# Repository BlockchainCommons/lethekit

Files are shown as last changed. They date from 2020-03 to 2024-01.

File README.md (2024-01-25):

# Blockchain Commons LetheKit

**Open source DIY hardware box for offline cryptographic tools**

### _by [Ken Sedgwick](https://www.github.com/ksedgwic), [Gorazd Kovacic](https://www.github.com/gorazdko), and [Christopher Allen](https://www.github.com/ChristopherA)_

* &nbsp;&nbsp; ***part of the [crypto commons](https://github.com/BlockchainCommons/crypto-commons/blob/master/README.md) technology family***
*  ***part of the [gordian](https://github.com/BlockchainCommons/gordian/blob/master/README.md) technology family***

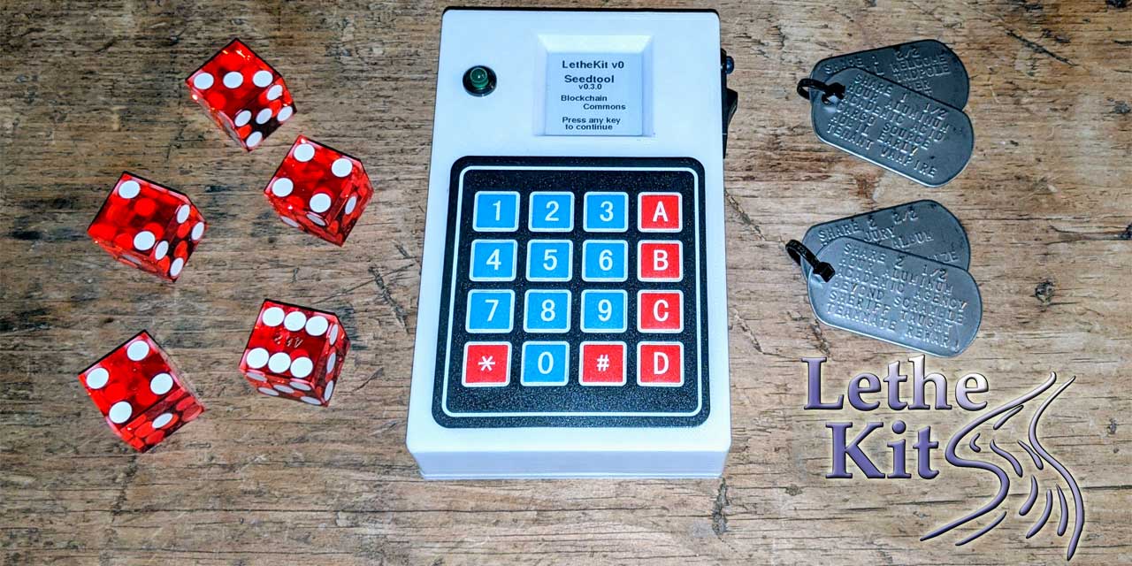
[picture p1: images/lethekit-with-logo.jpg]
LetheKit


*LetheKit* is a do-it-youself platform for performing various sensitive cryptographic operations on an offline airgapped device. It uses no WiFi or Bluetooth which could leak information and contains no local storage, and when the device is turned off it forgets any sensitive data stored in RAM. Thus the name Lethe (_lee-thee_), from the [mythological river](https://en.wikipedia.org/wiki/Lethe) of forgetfulness and oblivion.

## Additional Information

The following files contain everything you need to set up your *LetheKit* hardware and install its software.

* The [Parts List](doc/parts-list.md) describes all needed parts.
* The [Case Information](case) contains STL files for 3-D printing.
* The [Lethekit Assembly Instructions](doc/assembly.md) show how to put it together.
* The [Lethekit Installation Instructions](doc/installation.md) show how to install LetheKit in your Arduino development environment.
* The [Seedtool Installation Instructions](seedtool/doc/build.md) show to install Seedtool on your *LetheKit* using the Arduino IDE.
* The [Seedtool Application Instuctions](seedtool/README.md) describe how to generate and recover
[BIP-32](https://github.com/bitcoin/bips/blob/master/bip-0032.mediawiki) HD wallet master seeds in [BIP-39](https://github.com/bitcoin/bips/blob/master/bip-0039.mediawiki) and [SSKR](https://github.com/BlockchainCommons/Research/blob/master/papers/bcr-2020-011-sskr.md) formats.
* [Blog Post Overview](https://www.blockchaincommons.com/projects/Releasing-LetheKit/)

Your LetheKit can be charged or recharged with a micro-USB connection.

## Gordian Principles

**Gordian LetheKit** is a hardware exemplar meant to display the [Gordian Principles](https://github.com/BlockchainCommons/Gordian#gordian-principles), which are philosophical and technical underpinnings to Blockchain Commons' Gordian technology. This includes:

* **Independence.** LetheKit ensures that you're in total control of your seeds.
* **Privacy.** LetheKit is totally offline.
* **Resilience.** LetheKit depends on you for its resilience, since you must back up your words or codes.
* **Openness.** LetheKit communicates through airgaps via URs and QRs, for maximum interoperability.

Blockchain Commons apps do not phone home and do not run ads. Some are available through various app stores; all are available in our code repositories for your usage.

## Status - Unsupported

*LetheKit* is no longer being actively supported by Blockchain Commons. It may not be up to date with recent security notices, and it may not work as originally intended or even at all. This repo remains solely for historical purposes. Use at your own risk. 

If you'd like to become a new lead for the project, please file an issue.

## Origin, Authors, Copyright & Licenses

Unless otherwise noted (either in this [/README.md](./README.md) or in the file's header comments) the contents of this repository are Copyright © 2020 by Blockchain Commons, LLC, and are [licensed](./LICENSE) under the [spdx:BSD-2-Clause Plus Patent License](https://spdx.org/licenses/BSD-2-Clause-Patent.html).

In most cases, the authors, copyright, and license for each file reside in header comments in the source code. The table below attempts to attribute accurately for files without such information.

This table below also establishes provenance (repository of origin, permalink, and commit id) for files included from repositories that are outside of this one. Contributors to these files are listed in the commit history for each repository, first with changes found in the commit history of this repo, then in changes in the commit history of their repo of their origin.

| File | From | Commit | Authors & Copyright (c) | License |
| --- | --- | --- | --- | --- |
| Cryptosuite | [https://github.com/ksedgwic/Cryptosuite](https://github.com/ksedgwic/Cryptosuite) | ae0e3eeb4eb00c53fe235e0c34f77ade11f1982a | 2010 Peter Knight | <none> |
| bip39 | [https://github.com/ksedgwic/bip39](https://github.com/ksedgwic/bip39) | 9b8fa3c7d145c39558c2534f6cf40879477d93a1 | 2018 Chris Howe | [MIT License](https://github.com/ksedgwic/bip39/blob/master/LICENSE) |
| TRNG-for-ATSAMD51J19A-Adafruit-Metro-M4- | [https://github.com/SapientHetero/TRNG-for-ATSAMD51J19A-Adafruit-Metro-M4-](https://github.com/SapientHetero/TRNG-for-ATSAMD51J19A-Adafruit-Metro-M4-) | 17d5e36cd922ce7df8047d9c89633dca9b5ae122 | 2019 Ron Sutton | [MIT License](https://github.com/SapientHetero/TRNG-for-ATSAMD51J19A-Adafruit-Metro-M4-/blob/master/LICENSE.txt) |
| libwally-core | [https://github.com/ElementsProject/libwally-core](https://github.com/ElementsProject/libwally-core) | e0d0634aea716d813744326ea6c7590eb9fc381c | Jon Griffiths (Blockstream) 2016 | [BSD/MIT license](https://github.com/ElementsProject/libwally-core/blob/master/LICENSE) |
| Library-arduino-cbor | [https://github.com/jjtara/Library-Arduino-Cbor](https://github.com/jjtara/Library-Arduino-Cbor) | 996bf4a853513ee1fb94286691209a067c915bfb | jjtara 2014 | [Apache license](https://github.com/jjtara/Library-Arduino-Cbor/blob/master/LICENSE) |
| ArduinoSTL | [https://github.com/mike-matera/ArduinoSTL](https://github.com/mike-matera/ArduinoSTL) | 7411816e2d8f49d96559dbaa47e327816dde860c | Mike Matera 1999 | [GNU LGPL](https://github.com/mike-matera/ArduinoSTL/blob/master/LICENSE) |

### Dependencies

To build the *LetheKit* you'll need to use the following exterinal tools:

- [The Arduino IDE](https://www.arduino.cc/en/main/software)

The following internal Blockchain Commons projects are leveraged by *LetheKit*:

- [BlockchainCommons/bc-crypto-base](https://github.com/blockchaincommons/bc-crypto-base) — Well-Reviewed and Audited Cryptographic Functions for Use in Blockchain Commons Software Projects
- [BlockchainCommons/bc-shamir](https://github.com/BlockchainCommons/bc-shamir) - C Implementation of Shamir Secret Sharing for use in Blockchain Commons Software Projects
- [BlockchainCommons/bc-bytewords](https://github.com/BlockchainCommons/bc-bytewords) - C library for encoding and decoding Bytewords.
- [BlockchainCommons/bc-sskr](https://github.com/BlockchainCommons/bc-sskr) - Implementation of Sharded Secret Key Reconstruction (SSKR)

### Derived from ...

The *LetheKit* project was inspired by:

- [Bitcoin 2019 Conference Tutorial](https://github.com/arcbtc/bitcoin2019conf), by [Ben Arc](https://github.com/arcbtc), which provided a fully functional starting point using similar hardware.

### Used with ...

These are other projects that work with or leverage *LetheKit*.

- (submit a PR to this repo list your project)

## Financial Support

*LetheKit* (lee-thee kit) is a project of [Blockchain Commons](https://www.blockchaincommons.com/). We are proudly a "not-for-profit" social benefit corporation committed to open source & open development. Our work is funded entirely by donations and collaborative partnerships with people like you. Every contribution will be spent on building open tools, technologies, and techniques that sustain and advance blockchain and internet security infrastructure and promote an open web.

To financially support further development of *LetheKit* and other projects, please consider becoming a Patron of Blockchain Commons through ongoing monthly patronage as a [GitHub Sponsor](https://github.com/sponsors/BlockchainCommons). You can also support Blockchain Commons with bitcoins at our [BTCPay Server](https://btcpay.blockchaincommons.com/).

### Project Sponsors

Thanks to our project sponsors for their support of *LetheKit*:
  


[**Keystone**](https://keyst.one/) is the manufacturer of the Keystone Hardware Wallet and the Keystone Tablets. Their focus is on uncompromising security and ease of use, taking human error into consideration, skyrocketing attack costs, reducing burdens of proof, and avoiding single points of failure.
  
## Contributing

We encourage public contributions to this project through issues and pull requests! Please review [CONTRIBUTING.md](./CONTRIBUTING.md) for details on our development process. All contributions to this repository require a GPG signed [Contributor License Agreement](./CLA.md).

### Discussions

The best place to talk about Blockchain Commons and its projects is in our GitHub Discussions areas.

[**Gordian User Community**](https://github.com/BlockchainCommons/Gordian/discussions). For users of the Gordian reference apps, including [Gordian Coordinator](https://github.com/BlockchainCommons/iOS-GordianCoordinator), [Gordian Seed Tool](https://github.com/BlockchainCommons/GordianSeedTool-iOS), [Gordian Server](https://github.com/BlockchainCommons/GordianServer-macOS), [Gordian Wallet](https://github.com/BlockchainCommons/GordianWallet-iOS), and [SpotBit](https://github.com/BlockchainCommons/spotbit) as well as our whole series of [CLI apps](https://github.com/BlockchainCommons/Gordian/blob/master/Docs/Overview-Apps.md#cli-apps). This is a place to talk about bug reports and feature requests as well as to explore how our reference apps embody the [Gordian Principles](https://github.com/BlockchainCommons/Gordian#gordian-principles).

[**Blockchain Commons Discussions**](https://github.com/BlockchainCommons/Community/discussions). For developers, interns, and patrons of Blockchain Commons, please use the discussions area of the [Community repo](https://github.com/BlockchainCommons/Community) to talk about general Blockchain Commons issues, the intern program, or topics other than those covered by the [Gordian Developer Community](https://github.com/BlockchainCommons/Gordian-Developer-Community/discussions) or the 
[Gordian User Community](https://github.com/BlockchainCommons/Gordian/discussions).

### Other Questions & Problems

As an open-source, open-development community, Blockchain Commons does not have the resources to provide direct support of our projects. Please consider the discussions area as a locale where you might get answers to questions. Alternatively, please use this repository's [issues](./issues) feature. Unfortunately, we can not make any promises on response time.

If your company requires support to use our projects, please feel free to contact us directly about options. We may be able to offer you a contract for support from one of our contributors, or we might be able to point you to another entity who can offer the contractual support that you need.

### Credits

The following people directly contributed to this repository. You can add your name here by getting involved; the first step is to learn how to contribute from our [CONTRIBUTING.md](./CONTRIBUTING.md) documentation.

| Name | Role | Github | Email | GPG Fingerprint |
| --- | --- | --- | --- | --- |
| Christopher Allen | Principal Architect | [@ChristopherA](https://github.com/ChristopherA) | \<ChristopherA@LifeWithAlacrity.com\> | FDFE 14A5 4ECB 30FC 5D22  74EF F8D3 6C91 3574 05ED |
| Ken Sedgwick | Original Author, Occasional Contributor  | [@ksedgwic](https://github.com/ksedgwic) | \<ken@bonsai.com\> | 4695 E5B8 F781 BF85 4326 9639 BBFC E515 8602 5550  |
| Gorazd Kovacic | developer  | [@gorazdko](https://github.com/gorazdko)  | \<gorazdko@gmail.com\>  | 41F0 EA16 99A7 4C1E 2FA4 1B53 8CF9 6BC3 FF9D BBCE  |

## Responsible Disclosure

We want to keep all our software safe for everyone. If you have discovered a security vulnerability, we appreciate your help in disclosing it to us in a responsible manner. We are unfortunately not able to offer bug bounties at this time.

We do ask that you offer us good faith and use best efforts not to leak information or harm any user, their data, or our developer community. Please give us a reasonable amount of time to fix the issue before you publish it. Do not defraud our users or us in the process of discovery. We promise not to bring legal action against researchers who point out a problem provided they do their best to follow the these guidelines.

### Reporting a Vulnerability

Please report suspected security vulnerabilities in private via email to ChristopherA@LifeWithAlacrity.com (do not use this email for support). Please do NOT create publicly viewable issues for suspected security vulnerabilities.

The following keys may be used to communicate sensitive information to developers:

| Name | Fingerprint |
| --- | --- |
| Christopher Allen | FDFE 14A5 4ECB 30FC 5D22  74EF F8D3 6C91 3574 05ED |

You can import a key by running the following command with that individual’s fingerprint: `gpg --recv-keys "<fingerprint>"` Ensure that you put quotes around fingerprints that contain spaces.

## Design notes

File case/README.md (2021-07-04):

# LetheKit 3D Case

The LetheKit case can be 3D printed from the STL files in
this directory.  One print of each of the following is required:

* [body.stl](body.stl) — the main body of the LetheKit.

* [cover.stl](cover.stl) — the cover for the LetheKit.

* [shield.stl](shield.stl) — an internal component that protects the battery.

The case is designed with [Blender](https://www.blender.org):

* [case.blend](case.blend)

## Printing
### Printing Services
The following printing services have been used:

| Service | Material | Notes |
|---|---|---|
| [Hubs](https://hubs.com) | PA12 (SLS) 100&mu; | "thin walls" and "intersecting faces" warnings can be ignored |

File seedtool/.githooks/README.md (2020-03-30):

This set of git hooks maintains the state of `seedtool/gitrevision.h`.
In order to enable this feature one must execute the following command
anywhere in the seedtool directory:

    ./enable-gitrevision-hooks.sh

A default `seedtool/gitrevision.h` is checked in so folks who use a
tarball or other means will be able to compile.  It has placeholders
for the defined constants.

The `post-checkout`, `post-commit`, and `post-merge` hooks write the
following current information (samples below) to the
`seedtool/gitrevision.h` file:

```
#define GIT_BRANCH "revinfo"
#define GIT_SHORT_HASH "cdb54bd"
#define GIT_REV_COUNT "29"
#define GIT_LATEST_TAG "v0.1.0"
```

The `pre-commit` hook overwrites any generated `seedtool/gitrevision.h`
with the placeholders prior to commit so the placeholders version is
always checked in.

It is, of couurse, impossible to check in the correct current values
because those values depend on the hash of those value ...

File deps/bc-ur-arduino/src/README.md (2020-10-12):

## BC-UR-ARDUINO

This library is a version of https://github.com/BlockchainCommons/bc-ur ported to work
with Arduino.

## Status

Currently, it supports the UR/Fountain encoding, but decoding is not yet implemented.

## Dependencies

* [bc-crypto-base](https://github.com/BlockchainCommons/bc-crypto-base)
* [Library-Arduino-Cbor](https://github.com/jjtara/Library-Arduino-Cbor)
* [ArduinoSTL](https://github.com/mike-matera/ArduinoSTL)

Make sure to install the latest versions from Github.
I

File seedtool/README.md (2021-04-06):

# Seedtool Application Instructions

The *seedtool* utility allows you to generate and recover
[BIP-32](https://github.com/bitcoin/bips/blob/master/bip-0032.mediawiki)
HD wallet master seeds using
[BIP-39](https://github.com/bitcoin/bips/blob/master/bip-0039.mediawiki)
and
[SSKR](https://github.com/BlockchainCommons/Research/blob/master/papers/bcr-2020-011-sskr.md)
formats. In addition, it supports viewing extended keys and addresses in different formats.

This guide assumes you have successfully completed with [Seedtool Installation Instructions](doc/build.md).

## "No Seed" Functions

There are 4 ways to insert a seed into the *seedtool*:  
A - Generate seed with Dice  
B - Restore seed from BIP39  
C - Restore seed from SSKR  
D - Complete a randomly constructed BIP39 sentence

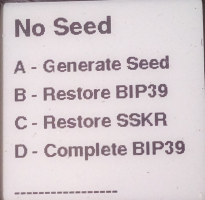
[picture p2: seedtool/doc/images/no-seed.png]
No Seed Menu


### Seed Generation with Dice

By rolling dice and typing the values, you can gather enough auditable entropy to generate a secure master seed. Rolling 50 dice gathers
roughly 128 bits of entropy.

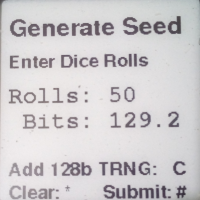
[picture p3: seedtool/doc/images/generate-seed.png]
Generate Seed


If you press C, 128 bits of TRNG entropy will be mixed in:

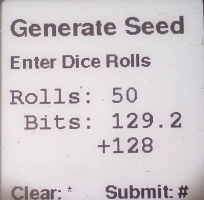
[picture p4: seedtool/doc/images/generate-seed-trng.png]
Generate Seed


### BIP-39 Key Recovery

You can insert a key into the *seedtool* by entering its BIP-39
recovery mnemonic passphrase.  From there you can generate SSKR
shares.

BIP-39 Restore

### SSKR Recovery

If you possess enough shares of a SSKR set, you can recover the
master seed with *seedtool*.  From there you can generate the BIP-39
mnemonic passphrase which will allow you to use it with most wallets.

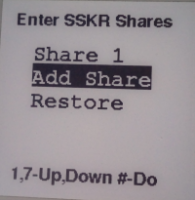
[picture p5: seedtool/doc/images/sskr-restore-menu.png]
SSKR Recovery Menu
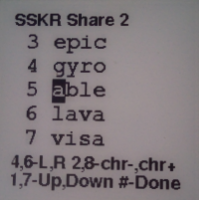
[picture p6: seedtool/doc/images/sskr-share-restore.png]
SSKR Share Entry
 

### Completing a randomly constructed BIP39 sentence

This is a way to generate your own seed without relying on hardware or software. See [instructions](doc/bip39_sentence_completion.md)

## Functions with a Seed

Once you have a seed through any of the prior flows, you can create
BIP-39 and SSKR mnemonic passphrases. In addition, you can view extended public and private
keys, wallet addresses etc. 

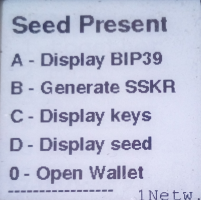
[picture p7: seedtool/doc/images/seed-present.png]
Seed Present Menu


### BIP-39 Generation

The BIP-39 phrase is displayed and can be backed up in a secure
offline fashion (e.g., hammering into metal).

BIP-39 View

### SSKR Generation

SSKR requires some configuration choices to determine total number of shares
and the required number of shares present to recover.

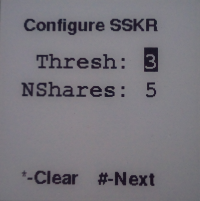
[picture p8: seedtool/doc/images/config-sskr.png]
SSKR Generation Config
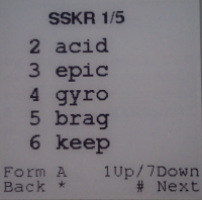
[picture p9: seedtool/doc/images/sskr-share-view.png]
SSKR Share View
 

You can choose among different formats:  
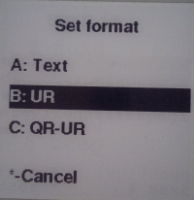
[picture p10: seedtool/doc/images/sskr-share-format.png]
SSKR Share Format

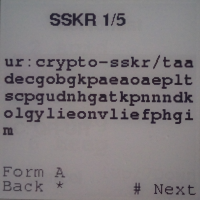
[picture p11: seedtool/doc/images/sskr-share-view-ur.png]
SSKR Share View UR
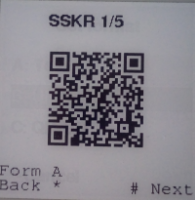
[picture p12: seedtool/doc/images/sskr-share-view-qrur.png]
SSKR Share View QRUR
 

### Displaying Keys

Extended public and private keys (XPUBs and XPRIVs) can be shown in different formats (base58, UR, QR) with different
options: slip132, with derivation path and privkey. If privkey is selected, an extended private key (XPRIV) is shown. Derivation path can be manually set or chosen among standard ones: *native segwit*, *nested segwit* and *cosigner*. Cosigner is the one that can be used in multisignature setups.

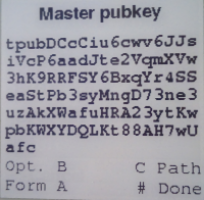
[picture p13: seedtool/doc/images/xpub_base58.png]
XPUB BASE58

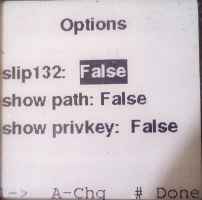
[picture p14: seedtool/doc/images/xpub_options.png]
XPUB OPTIONS

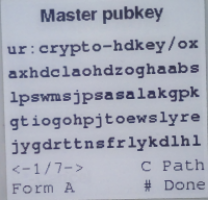
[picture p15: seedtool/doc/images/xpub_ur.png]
XPUB UR


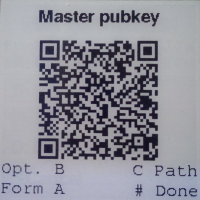
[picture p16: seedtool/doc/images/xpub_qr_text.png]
XPUB OPTIONS

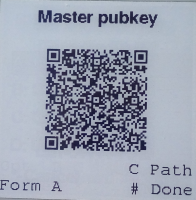
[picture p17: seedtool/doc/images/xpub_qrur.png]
XPUB OPTIONS

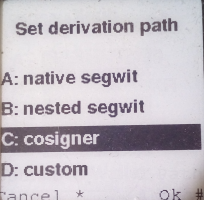
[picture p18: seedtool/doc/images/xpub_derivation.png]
XPUB DERIVATION


### Displaying Seed

You can choose to export seed in UR or QR-UR format.

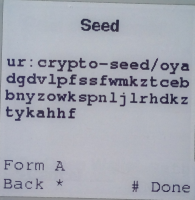
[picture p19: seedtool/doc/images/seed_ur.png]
seed ur

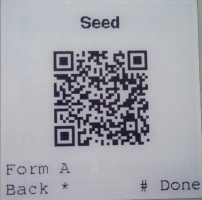
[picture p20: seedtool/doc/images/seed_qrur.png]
seed qrur


### Displaying Addresses

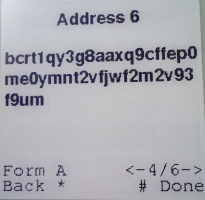
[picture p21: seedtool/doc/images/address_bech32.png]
ADDR TEXT
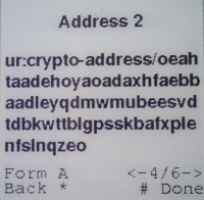
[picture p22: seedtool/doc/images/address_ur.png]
ADDR ur
 
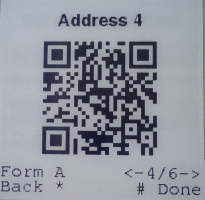
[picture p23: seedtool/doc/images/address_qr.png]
ADDR qr
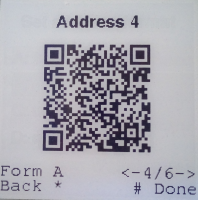
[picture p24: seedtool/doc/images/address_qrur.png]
ADDR qrur
 
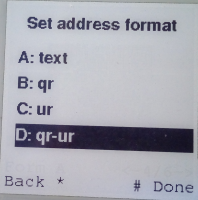
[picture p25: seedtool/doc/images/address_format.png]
ADDR format


A wallet can be exported in the 4 different formats (text, QR, UR and QR-UR):

wallet export wallet export text
wallet export text wallet export text

### Setting network

By pressing 1 in `Seed Present` menu, you can choose among `mainnet`, `testnet` and `regtest`:

wallet export text

## Common Workflows

There are several common key management workflows that *seedtool* is
useful for.

### Generate a New Wallet

By using dice to generate a BIP-39 mnemonic passphrase, you can avoid
trusting a particular hardware vendor's hardware.
[See: RNG subversion](https://en.wikipedia.org/wiki/Random_number_generator_attack#RNG_subversion)

To execute this flow with *seedtool*:
1. Generate a new master seed using 50+ die rolls.
2. Record your master BIP-39 backup in a secure manner (hammer into metal).
   This BIP-39 backup may be restored into most other wallets for common use.
3. Optionally create a SSKR sharded backup set which can serve as
   long-term cold storage.
   
### Generate a SSKR Backup Set for an Existing Wallet

If you've already got a wallet in use, and have the BIP-39 backup for
it, you can generate a SSKR backup set as well:
1. Restore your seed in *seedtool* using your BIP-39 backup.
2. Create a SSKR sharded backup.

### Recover a Master Seed from SSKR Backup Shards

If you need to recover your master seed and have enough shards from a
SSKR backup set:
1. Recover the master seed from the SSKR shards.
2. Create a BIP-39 mnemonic which may then be directly restored into
   most wallets for use.

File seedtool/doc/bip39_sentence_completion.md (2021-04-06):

## BIP39 Sentence Completion

Option `D` (`Complete BIP39`) allows you to
complete a randomly constructed BIP39 sentence. This means that your seed, keys and wallet creation does not rely on hardware nor software but entirely on a randomized procedure conducted by yourself tossing coins. It is true however that the LetheKit completes the last word, i.e. `checksum word`, so that mnemonic sentence can be correctly parsed.



### Procedure

First print out the following table and prepare a coin.



To randomly choose a BIP39 word you have to toss a coin 11 times and fill out a row in the table. For heads you can write 1 and for tails 0.

For example if your first eleven throws are:

`heads` `tails` `tails` `heads` `tails` `heads` `heads` `tails` `tails` `tails` `heads`

then your first row should look like this:



Coin tosses in every row represent a binary number which can be converted to a BIP39 word with the help of a [lookup table](https://www.rudefox.io/custody/walkthrough/create-seed/lookup-tables.pdf)



You have to repeat the procedure 12 times to fill out the table and obtain a full mnemonic sentence of 12 words. Then input all the words into LetheKit



When `done` LetheKit will ask you if your procedure was truly randomized.

⚠️ : If the procedure is not randomized, i.e. the words are not obtained by flipping a coin, the mnemonic sentence is insecure and leads to a loss of funds.



After confirmation, LetheKit will show you the completed BIP39 sentence, i.e. the last word (i.e. `checksum word`) will be transformed to make the sentence complete, while the first eleven words will stay the same.



At this point you have to update the last word on your sheet:



When done, LetheKit will ask you whether you have updated the last word on your sheet?



By confirming with `yes`, LetheKit will generate a seed, keys and a wallet.

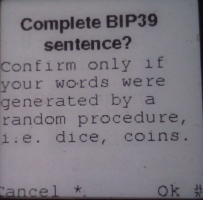
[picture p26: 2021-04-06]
seedtool/doc/images/complete_bip39.png

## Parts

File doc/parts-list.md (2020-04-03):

LetheKit Parts List
================================================================

| Supplier | Description | Quantity | Price |
|---|---|---:|---:|
| Waveshare  | [Waveshare 200x200, 1.54inch E-Ink display module](https://www.waveshare.com/1.54inch-e-paper-module.htm) | 1 | $15.99 |
| AliExpress | [16 Key Membrane Switch Keypad](https://www.aliexpress.com/item/32874565775.html) | 1 |  $0.60 |
| SparkFun | [SparkFun Thing Plus - SAMD51](https://www.sparkfun.com/products/14713) | 1 | $19.95 |
| SparkFun | [Lithium Ion Battery - 2Ah](https://www.sparkfun.com/products/13855) | 1 | $12.95 |
| SparkFun | [LED - Basic Green 5mm](https://www.sparkfun.com/products/9592) | 1 |  $0.35 |
| SparkFun | [LED - Basic Blue 5mm](https://www.sparkfun.com/products/11372) | 1 |  $0.55 |
| SparkFun | [LED Holder - 5mm](https://www.sparkfun.com/products/11840) | 2 |  $1.00 |
| SparkFun | [Jumper Wires](https://www.sparkfun.com/products/12796) | 1 |  $1.95 |
| SparkFun | [Break Away Male Headers - Right Angle](https://www.sparkfun.com/products/553) | 1 |  $1.95 |
| Pololu | [Rocker Switch](https://www.pololu.com/product/1406) | 1 |  $0.75 |
| McMaster | [Flat Head Thread-Forming Screws, No. 6, 1/2"](https://www.mcmaster.com/96068a153) | 4 |  $0.23 |
| McMaster | [Phillips Rounded Head Thread-Forming Screws, No. 2, 3/16"](https://www.mcmaster.com/99461A710) | 6 |  $1.46 |
| McMaster | [Push-In Bumpers](https://www.mcmaster.com/9544k12) | 4 |  $0.30 |
| | [3D Printed Case](../case/README.md) | 1 | |
| | [3D Printed Cover](../case/README.md) | 1 | |
| | [3D Printed Battery Shield](../case/README.md) | 1 | |
| | **TOTAL** | | $58.03 |

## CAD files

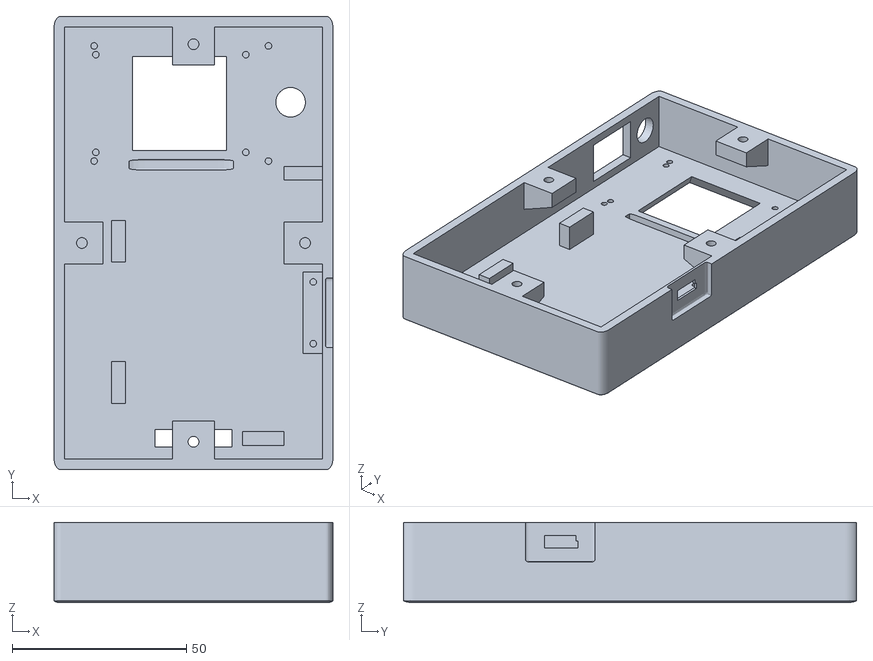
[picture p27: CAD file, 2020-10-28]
case/body.stl
80.0 x 130.0 x 23.0

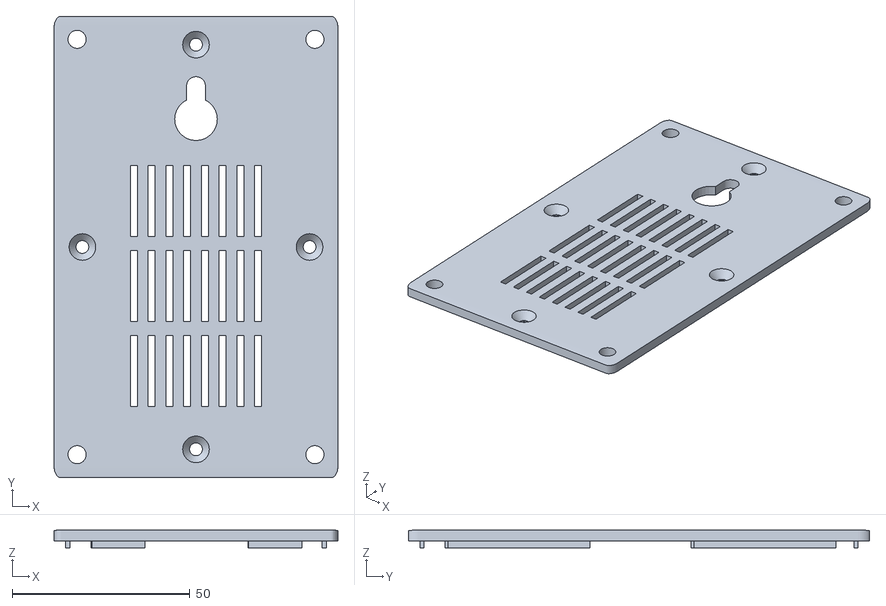
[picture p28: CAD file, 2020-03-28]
case/cover.stl
80.0 x 130.0 x 5.00

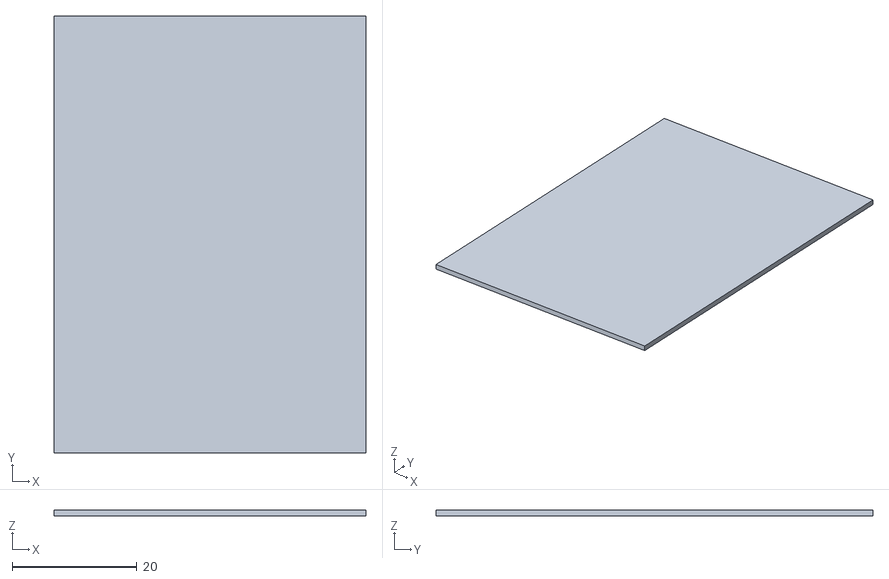
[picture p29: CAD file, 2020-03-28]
case/shield.stl
50.0 x 70.0 x 1.00

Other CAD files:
case/case.blend

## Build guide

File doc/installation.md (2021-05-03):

## LetheKit Installation Instructions

These instructions describe how to install LetheKit into your local
development environment.

LetheKit provides a collection of security modules (libraries) that
work well together. You install them into your local Arduino
development environment and then build the provided sample applications or
develop your own applications before uploading them to your SAMD51.

### Installing Arduino IDE

If you don't already have the *Arduino IDE* installed (recommended v1.8.13) in your local development environment, here are the instructions:

- For macOS we recommend using `$ brew cask install arduino` which will install the Arduino.app in your `/Applications/` folder.
- For Linux users we recommend installing with:
```bash
$ wget https://downloads.arduino.cc/arduino-1.8.13-linux64.tar.xz
$ tar -xvf arduino-1.8.13-linux64.tar.xz
$ cd arduino-1.8.13
$ ./install.sh # sudo ./install.sh
```

### Installing Toolchain for SAMD51

This is an excerpt from [SAMD51 Thing Plus Hookup Guide](https://learn.sparkfun.com/tutorials/samd51-thing-plus-hookup-guide/setting-up-the-arduino-ide):

- In the Arduino IDE, open **Preferences** (**Arduino** > **Preferences**), find the  **Additional Board Manager URLs** text box, and copy this  URL to it and click OK.
  -  `https://raw.githubusercontent.com/sparkfun/Arduino_Boards/master/IDE_Board_Manager/package_sparkfun_index.json`
- Now we need to install the correct Arduino SAMD Core. Navigate to your **Board Manager** (**Tools** > **Board**: > **Boards Manager...**), then find an entry for **Arduino SAMD Boards (32-bits ARM Cortex-M0+)**. It may help to enter `SAMD` into the search bar. Select that Arduino core and install the latest version.
- Now we need to install the **SparkFun SAMD** Add-on. Enter `sparkfun samd` in the **Board Manager**'s search bar, which should show **SparkFun SAMD Boards**. Install it.
- Now select from the **Tools** > **Board**: > list, choose **SparkFun SAMD51 Thing Plus**. Now when you look at the **Tools** menu you should see this board selected as default.
- Connect the LetheKit to your computer and turn it on, and then navigate back up to the **Tool** > **Port** menu. The port menu should magically know which of your ports is the SAMD51 Thing Plus board.

### Installing LetheKit on your system

Clone the git repository anywhere you like and install LetheKit:

```bash
$ git clone --recursive https://github.com/BlockchainCommons/lethekit
$ cd lethekit
$ export LK_ROOT=`pwd` && $LK_ROOT/scripts/install-lethekit $LK_ROOT
```

The installation script creates symbolic links in
`Arduino/Libraries` which point back to the appropriate
dependencies in `$LK_ROOT/deps`.

#### Notes

It's safe to re-run the installation at any time.

If you move your LetheKit source tree or pull new changes in from Github, just run the installation
script again:

```bash
$ cd lethekit
$ export LK_ROOT=`pwd` && $LK_ROOT/scripts/install-lethekit $LK_ROOT
```

### Next steps

Proceed to [Seedtool Installation Instructions](../seedtool/doc/build.md) to compile and install the `seedtool` firmware on your LetheKit.

<!-- TODO
If you want to uninstall LetheKit use the installation script with
the `--uninstall` option:

    # Uninstall LetheKit
    # FIXME - implement this!
    $LK_ROOT/scripts/install-lethekit --uninstall $LK_ROOT $ARDUINO_ROOT

It's safe to move your Arduino sketchbook at any time; LetheKit
should remain installed.

If you upgrade LetheKit in the future use the `--upgrade` option to
the install script after upgrading LetheKit:

    # After upgrading LetheKit
    # FIXME - implement this!
    $LK_ROOT/scripts/install-lethekit --upgrade $LK_ROOT $ARDUINO_ROOT
-->

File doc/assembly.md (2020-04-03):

## LetheKit Assembly Instructions

The following steps fully detail how to assemble the LetheKit from its parts.

### Assemble the Switch Harness

_Parts:_ Jumper Wires, Rocker Switch

1. Separate (pull apart) a black/white pair from the **Jumper Wires**.
   Cut this pair in the middle and strip 1cm of the ends on one of the
   halves.

2. Separate a brown wire from the jumper wires. Cut this wire in the
   middle and strip 1cm of the ends on both halves.
   
3. Twist the stripped black lead together with the two stripped brown
   leads and solder to post "1b" on the **Rocker Switch** (under the "1" part of
   the switch).

4. Solder the white lead to the center post of the rocker switch.

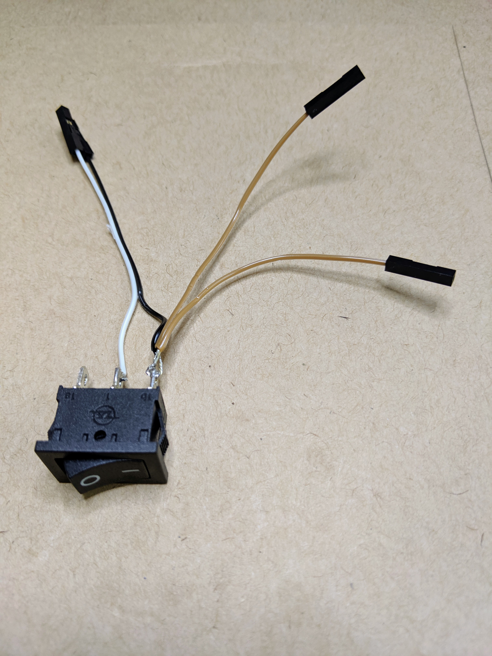
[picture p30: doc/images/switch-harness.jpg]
Switch Harness


### Assemble the Waveshare Display Harness

_Parts:_ Waveshare 200x200 Display Module, (optional) Cable Ties

1. The **Display Module** comes with a cable that has a display connector
   on one end and individual jumper connectors on the other.  Attach
   the display connector end to the display.
   
2. It's helpful to add a small **Cable Tie** (or similar) to the middle of
   the cable cluster to help keep the wires together.

### Connect the SAMD51 Headers

_Parts:_ Break Away Male Headers, SAMD51

1. Break the **Break Away Male Headers** into a 12-pin piece and a 16-pin
   piece.
   
2. Solder the headers onto the top of the **SAMD51** with the pins
   facing away from the board.
   
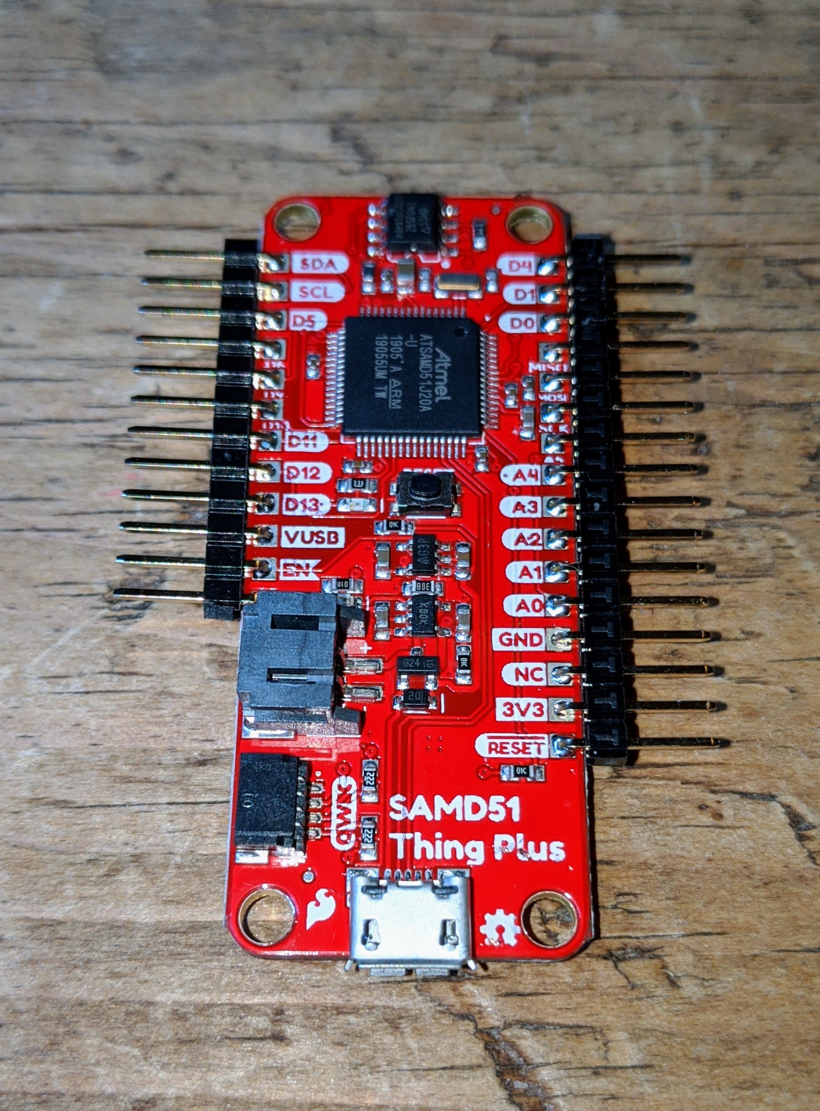
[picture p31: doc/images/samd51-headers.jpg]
SAMD51 Headers


#### Add a Jumper to SAMD51

An extra ground pin is required on the SAMD51 header.  Luckily, there is
an unused (not-connected) pin that can be commandeered.

_Parts:_ connected SAMD51 with Headers

1. Solder a piece of wire bridging the GND and NC pins on the bottom
   of the **SAMD51**.

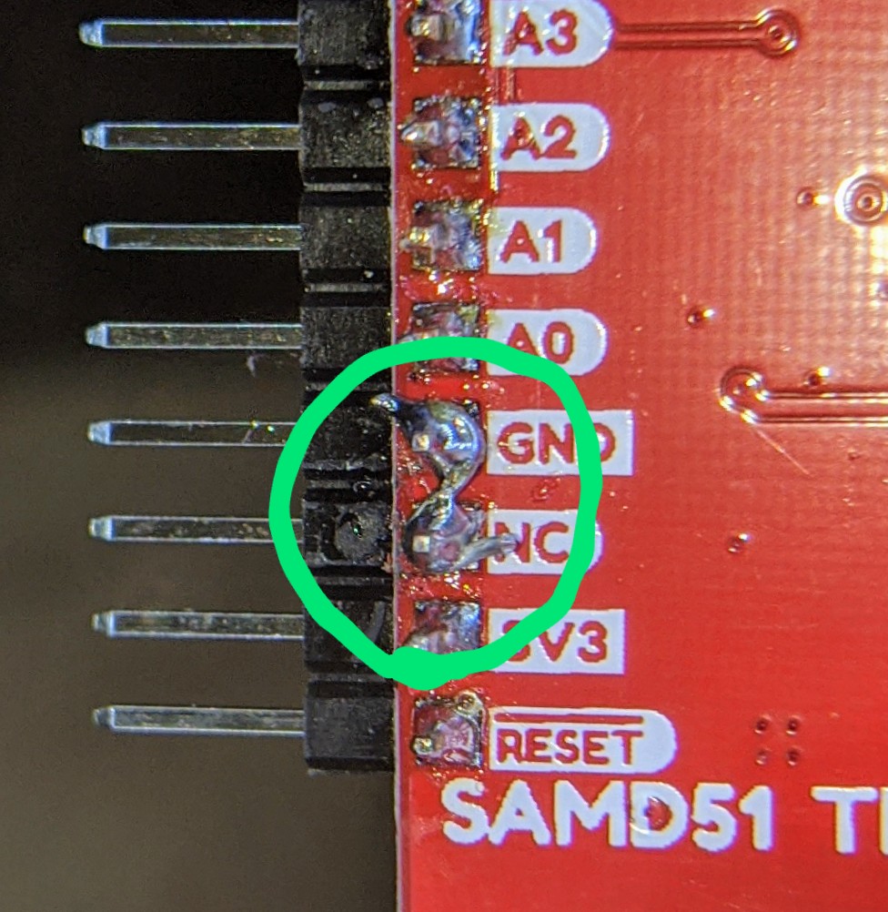
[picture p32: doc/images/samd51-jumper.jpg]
SAMD51 Jumper


### Attach Display Harness to SAMD51

_Parts:_ assembled Waveshare Display Harness, connected SAMD51 with Headers

1. Attach the **Waveshare Display Harness** to the **SAMD51** as shown
   in the picture.

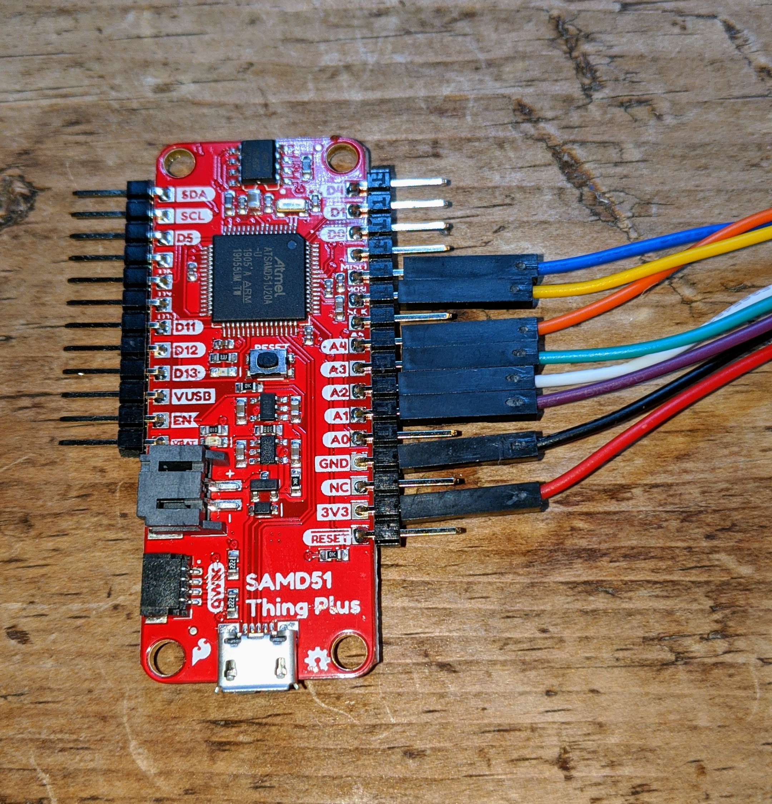
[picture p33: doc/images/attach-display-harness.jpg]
Attach Display


### Assemble LED Wires

_Parts:_ Jumper Wires, connected SAMD51 with Headers

1. Separate a blue and green pair from the **Jumper Wires**.  Split the
   pair most of the way to one side.
   
2.  Attach the non-split side of the pair to the **SAMD51** as
    shown.

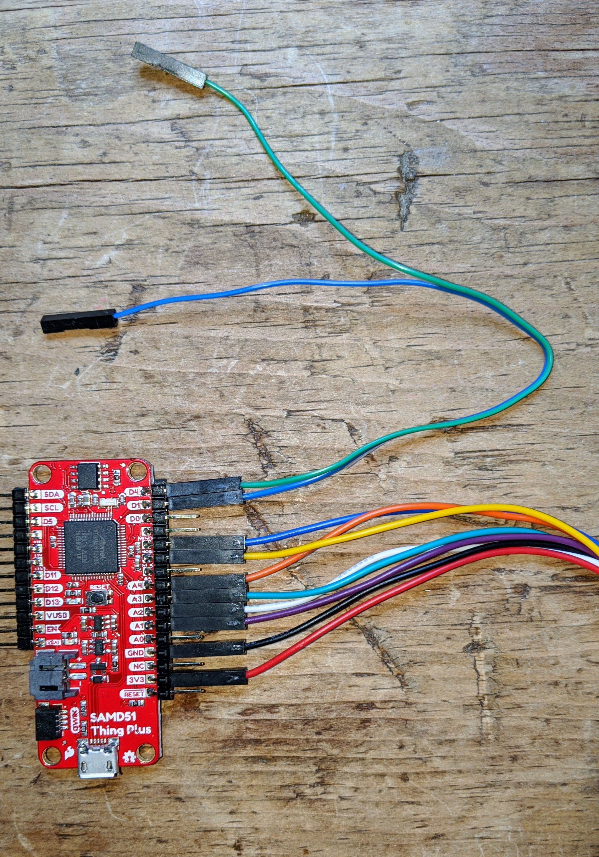
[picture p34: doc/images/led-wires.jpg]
LED Wires

    
### Attach Keypad to Case

_Parts:_ Membrane Switch Keypad, 3D Printed Case

1. Insert the **Membrane Switch Keypad** connector through the slot at the bottom of the
   **Case** front.
   
2. Peel the adhesive cover off the back of the Keypad and press it
   into place on the Case as shown.
   
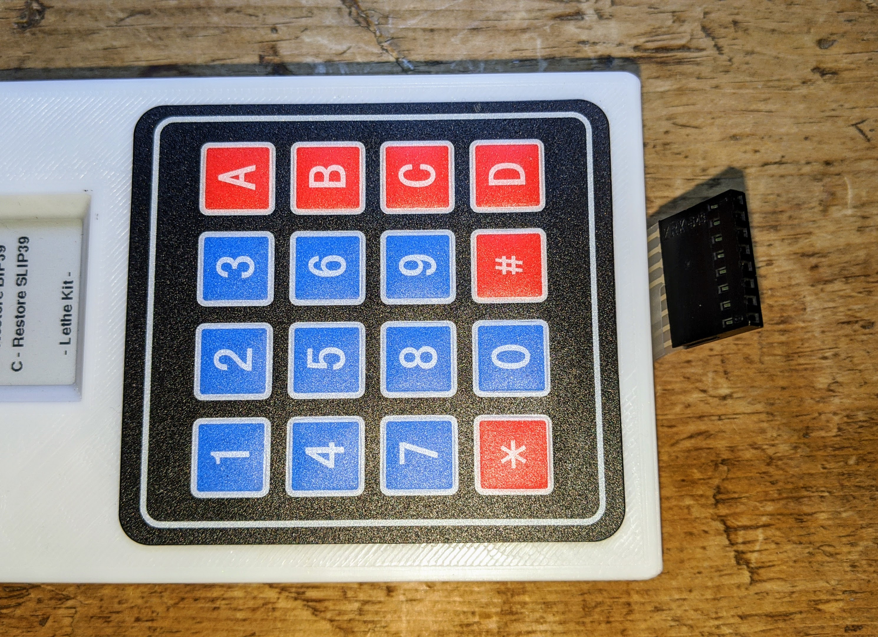
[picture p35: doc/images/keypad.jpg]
Keypad


### Attach Display to Case

_Parts:_ Waveshare 200x200 Display Module, 3D Printed Case, 3/16" Phillips Rounded Head Screws

1. Gently attach the **Display Module** to the **Case** with **Phillips Rounded Head Screws**.  DO NOT OVERTIGHTEN
   SCREWS. There are two sets of display holes to support an alternate
   display; use the set which aligns the display in its cutout when
   viewed from the other side of the case.
   
2. It's helpful to dress the display wires towards the bottom of the
   case as they leave the display connector so that they will clear the
   LED when it is inserted through the hole.
   
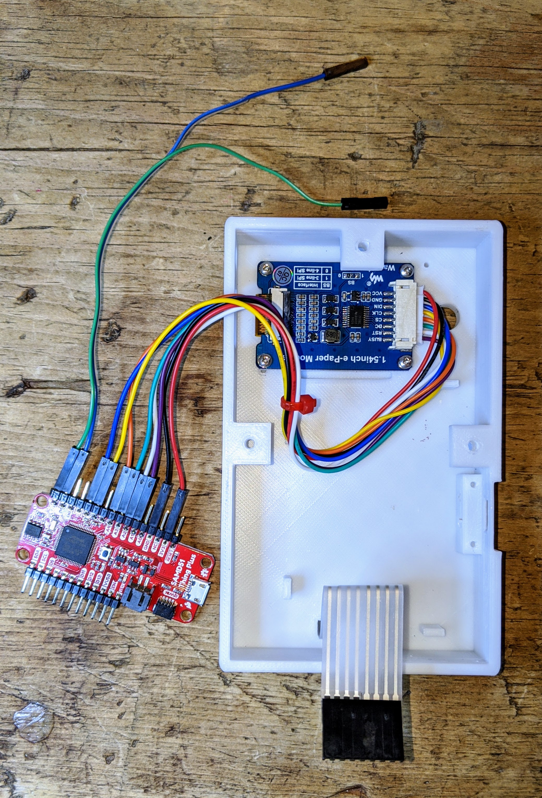
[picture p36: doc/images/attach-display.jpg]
Attach Display

   
### Attach LEDs to Case

_Parts:_ Blue LED, Green LED, LED Holders, 3D Printed Case

1. Trim the **LED** leds a little. Trim the longer lead to 18mm length
   from the base of the LED and the shorter lead to 16mm.  The lead
   length is used to identify polarity so it's critical to keep the
   longer lead longer than the shorter lead.

2. Insert the **Blue LED** into an **LED holder** and snap it into place in the
   hole in the side of the **Case**, above where the power switch will go.
   It's helpful if the LED's leads are horizontally oriented.
   
3. Insert the **Green LED** into an **LED holder** and snap in into place in the
   hole in the front of the case.  Bend the leads in a 90-degree angle,
   down towards the bottom of the case. Again, it's helpful if the
   leads are oriented horizontally.
   
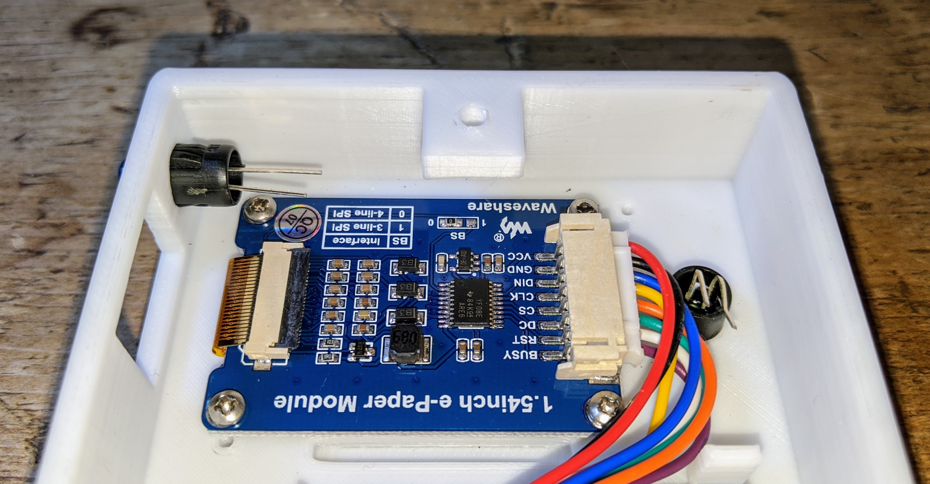
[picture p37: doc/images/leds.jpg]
LEDs


### Attach the Switch to Case

_Parts:_ Rocker Switch, Switch Harness, 3D Printed Case, assembled SAMD51 with Headers

1. Snap the **Rocker Switch** into place in the **Case**.  Orient the Rocker Switch so the
   "1" side is towards the top of the case.
   
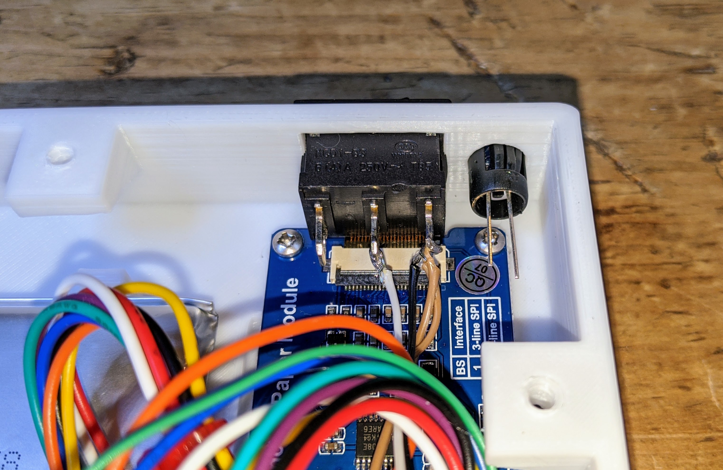
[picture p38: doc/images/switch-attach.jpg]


2. Connect the white and black **Switch Harness** leads to the **SAMD51** as
   shown.
   
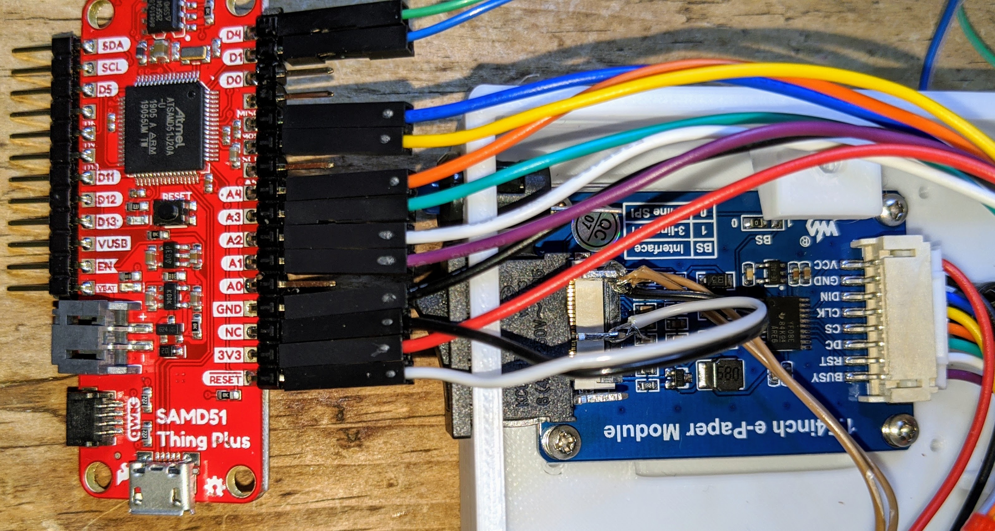
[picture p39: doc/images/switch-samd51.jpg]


### Insert Battery

_Parts:_ Lithium Ion Battery, 3D Printed Case

1. Place the **Lithium Ion Battery** into the guides in the **Case** as shown.

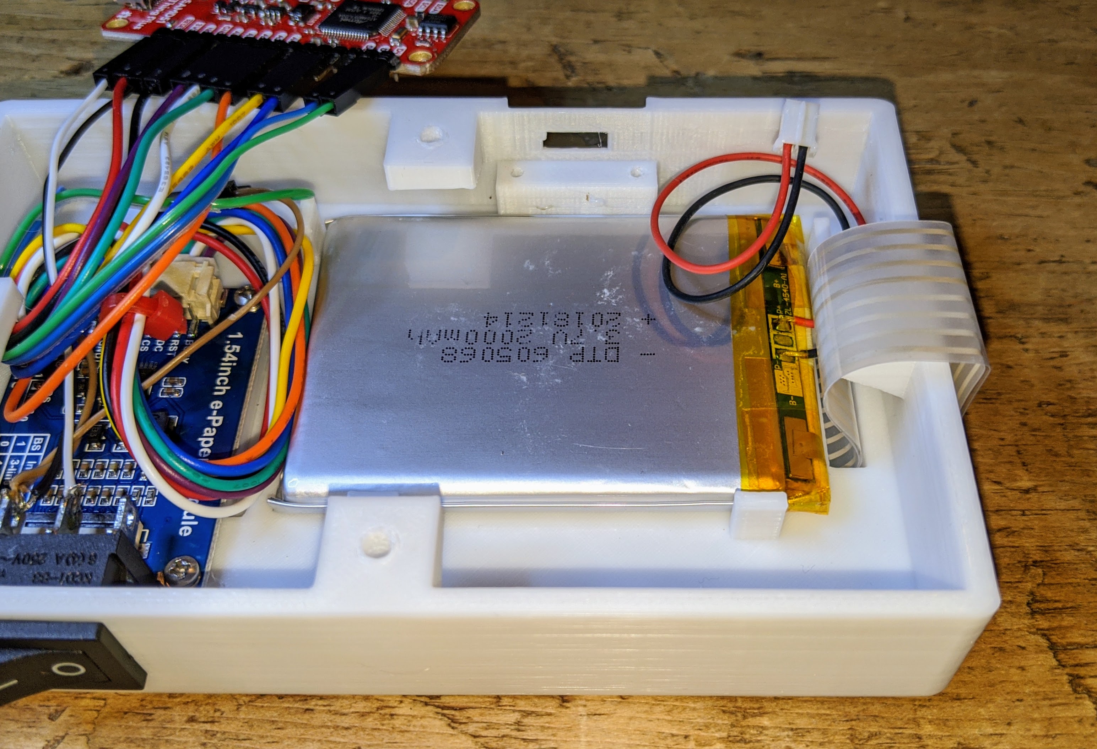
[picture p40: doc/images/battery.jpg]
Battery


### Install Battery Shield

The shield prevents the SAMD51 module from damaging the surface of the
battery.

_Parts:_ 3D Printed Battery Shield

1. Place the **Battery Shield** on top of the battery in the guides as shown.

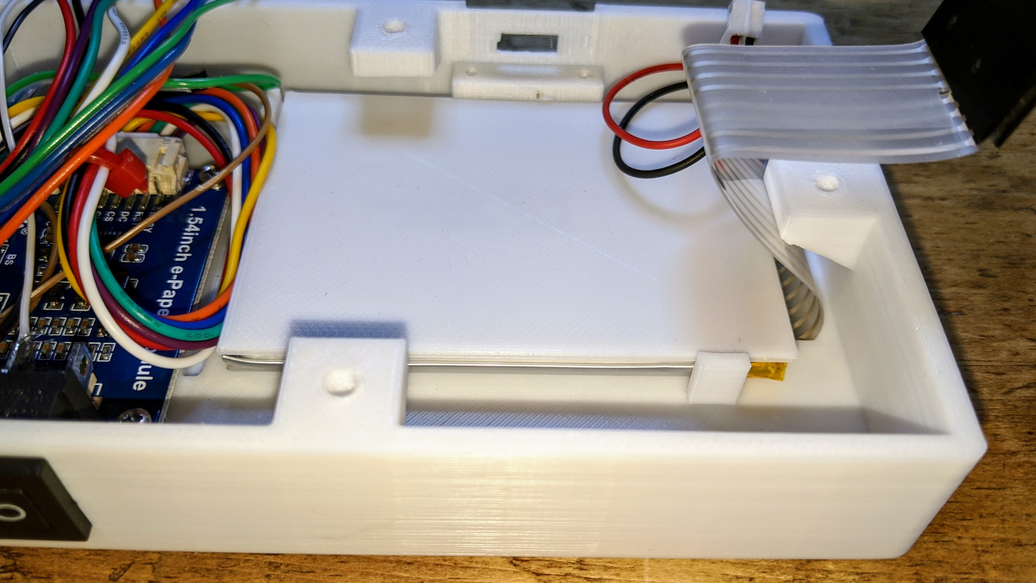
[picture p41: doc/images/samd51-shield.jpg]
Shield


### Connect the Keypad Connector

_Parts:_ Membrane Switch Keypad, assembled SAMD51 with Headers

1. Connect the the **Membrane Switch Keypad** connector to the **SAMD51** as shown. Note that the
   connector fits "one pin in" from the end of the header.

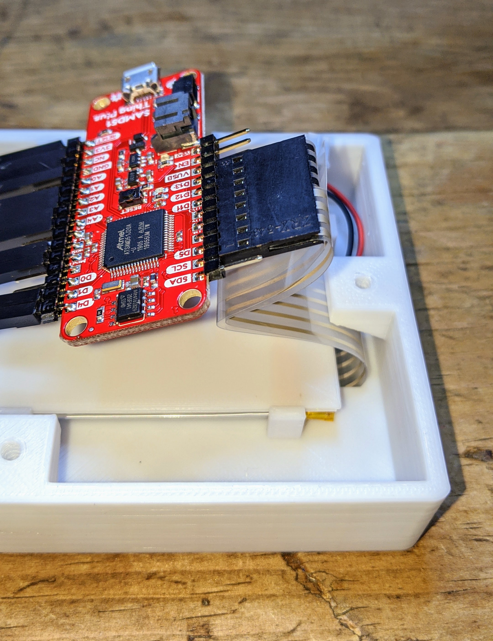
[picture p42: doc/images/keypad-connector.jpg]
Keypad Connector


### Attach SAMD51 to Case

_Parts:_ assembled SAMD51 with Headers, 3D Printed Case, 3/16" Phillips Rounded Head Screws

1. Fit the **SAMD51** into is mounting location on the **Case**.  Attach with **Phillips Rounded Head Screws*8.  DO
   NOT OVERTIGHTEN THE SCREWS.

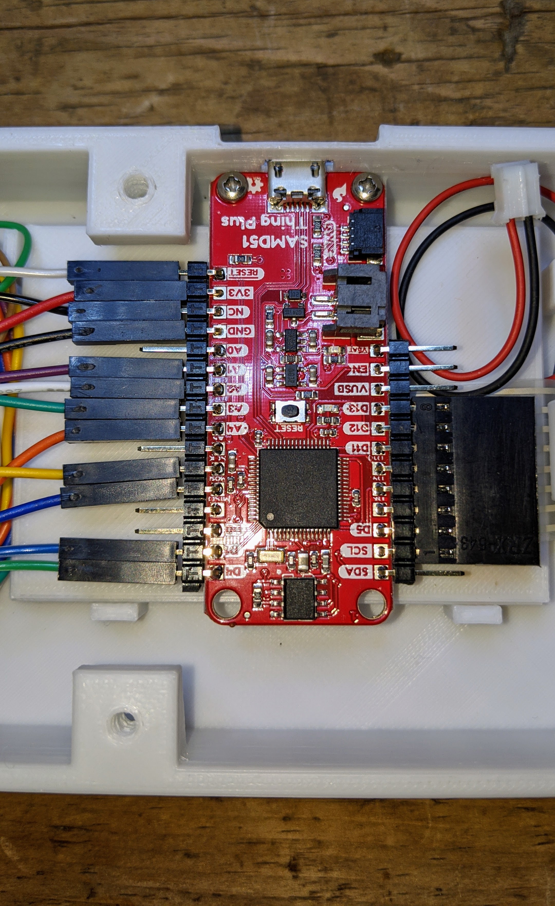
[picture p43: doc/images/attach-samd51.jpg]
Attach SAMD51


### Connect LEDS

_Parts:_ Blue LED, Green LED, LED Wires, Switch Harness

1. Connect the green wire from the **LED Wires** to the longer lead of the **Green LED**.

2. Connect the blue wire from the **LED Wires** to the longer lead of the **Blue LED**.

3. Connect one of the brown wires from the **Switch Harness** to the shorter lead of the **Green LED**.

4. Connect the other brown wires from the **Switch Harness** to the shorter lead of the **Blue LED**.

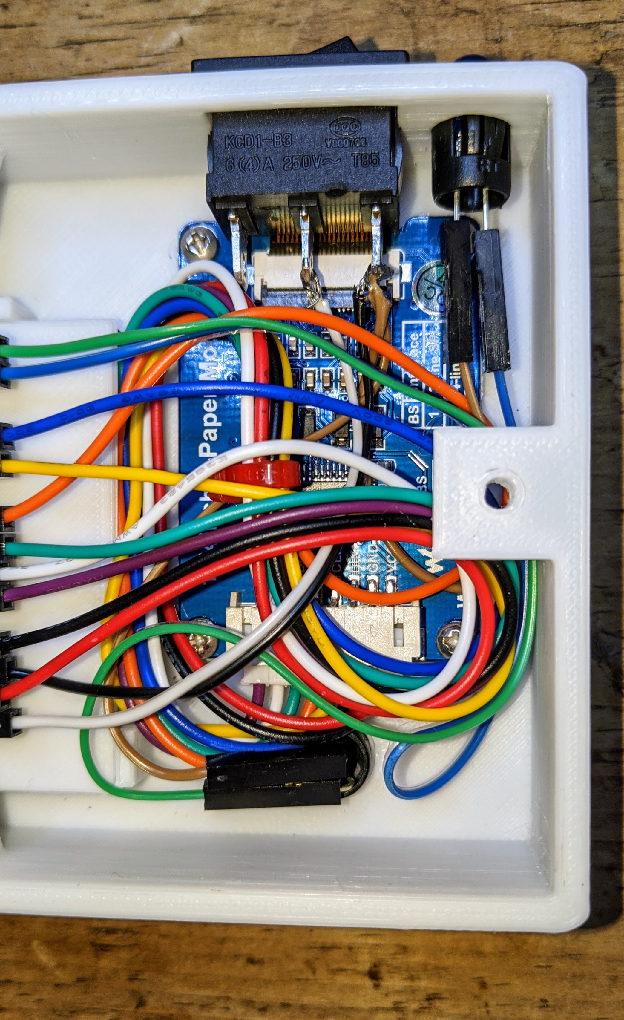
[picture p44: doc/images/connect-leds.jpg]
Connect LEDs


### Connect Battery

_Parts:_ Lithium Ion Battery, assembled SAMD51 with Headers

1. Carefully connect the **Lithium Ion Battery** to the **SAMD51**.  Support the SAMD51 as you insert the connector to avoid stressing the attachment screws.
   
**IMPORTANT** - Always first disconnect the battery when working on
the inside of the terminal to avoid damaging the cicuits.

#### That's It!

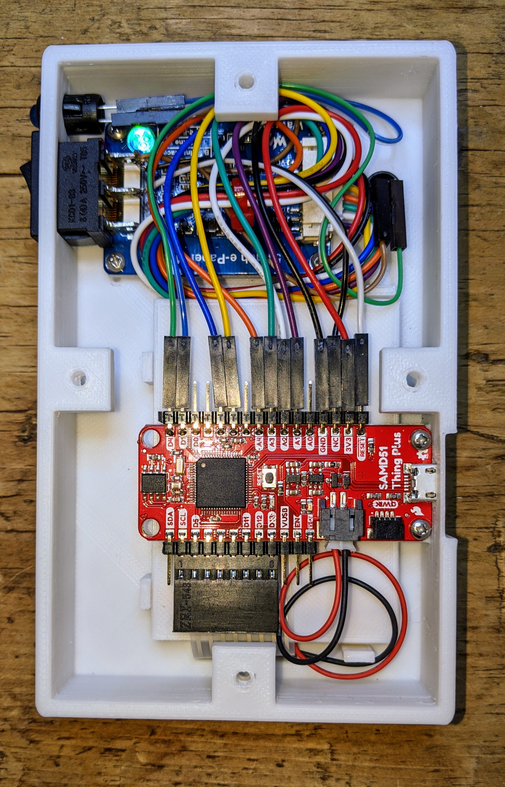
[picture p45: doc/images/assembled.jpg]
Assembled


#### Attach the Cover

_Parts:_ 3D Printed Cover, Push-in Bumpers, 1/2" Flat Head Screws

1. Press the **Bumpers** into the **Cover**.

2. Attach the **Cover** to the **Case** with the **1/2" Flat Head Screws**.

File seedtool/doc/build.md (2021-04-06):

# Seedtool Installation Instructions

This guide assumes you have successfully completed
[LetheKit Installation Instructions](../../doc/installation.md)

### Open project in Arduino IDE

Launch the Arduino IDE, click `File->Open`,
locate `seedtool` directory and double click on the `seedtool.ino`.

*Note:* Make sure you have installed libraries required by LetheKit.
Navigate to your Library Manager (**Tools** > **Manage Libraries…**)
  * `Adafruit GFX Library`
  * `Keypad`
  * `QRCode`





### Build and Upload *seedtool*

Connect a LetheKit hardware device to an appropriate USB port.

To upload code to the SAMD51 module you will need to [enter the
bootloader mode](#entering-bootloader) and press the `Upload` button on the Arduino IDE. The *seedtool*
application will be built and uploaded to your device.



You should see LetheKit refreshing its screen and starting selftest. Selftest can be skipped by holding any key.
on the keypad.

*Note:* once you enter the bootloader mode it may take some moments for your system
to recognize your device and port again. Uploading immediately may result in error.

### Next steps

Proceed to [Seedtool Application Instructions](../README.md) for information on using the *seedtool*.

### Entering Bootloader

#### Approach 1

Press the reset button twice in rapid succession. The blue LED
will start glowing bright.



[Source](https://learn.sparkfun.com/tutorials/samd51-thing-plus-hookup-guide/setting-up-the-arduino-ide)

#### Approach 2

It is also possible to enter bootloader mode by power cycling with the
external power switch.  Here are the steps for the external power
switch method:

1. Connect the LetheKit to a USB port on you computer. Turn the
   LetheKit on and wait a few seconds.

2. Turn off, on, off, on rapidly.

3. If the device is in bootloader mode, the blue power light will not
   be on, even though it is plugged in and the switch is left in the
   "on" position.

### For Developers

#### Install gitrevision.h

The `gitrevision.h` file is generated with git hooks and contains the
latest version information, allowing that information to be built into the application and
reported to the user.  It is not critical, but is very helpful when
reporting bugs, requesting features etc.

Enable the generation of the `gitrevision.h` file.  This only needs to
be done once, but is safe to do anytime you like.

```bash
# Must be run in the seedtool directory
./enable-gitrevision-hooks.sh
```

You may disable `gitrevision.h` generation with:
```bash
$ ./disable-gitrevision-hooks.sh
```

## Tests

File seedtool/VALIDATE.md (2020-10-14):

#### Generate Seed

    "123456"

#### Restore BIP39

     1 mirror
     2 reject
     3 rookie
     4 talk
     5 pudding
     6 throw
     7 happy
     8 era
     9 myth
    10 already
    11 payment
    12 owner

#### Restore SSK (2 out of 3)

Note: Each generation of SSKR shares (using the same binary seed) leads to different combination of words.
However, the restoration of these words should always lead back to the same binary seed.

    Share #1
     1 tuna   6 gyro   11 zone   16 runs   21 waxy   26 buzz
     2 acid   7 able   12 jazz   17 dark   22 zone   27 horn
     3 epic   8 acid   13 draw   18 menu   23 body   28 luau
     4 gyro   9 able   14 pool   19 luau   24 veto   29 tiny
     5 cost   10 news  15 jump   20 hard   25 meow
     
    Share #2
     1 tuna   6 gyro   11 whiz   16 scar   21 gala   26 zone
     2 acid   7 able   12 very   17 also   22 huts   27 cost
     3 epic   8 acid   13 stub   18 jowl   23 what   28 into
     4 gyro   9 acid   14 join   19 idea   24 knob   29 ugly
     5 cost   10 help  15 inky   20 yawn   25 song

    Share #3
     1 tuna   6 gyro   11 visa   16 fuel   21 rock   26 cook
     2 acid   7 able   12 join   17 iris   22 ugly   27 slot
     3 epic   8 acid   13 yurt   18 judo   23 soap   28 next
     4 gyro   9 also   14 echo   19 fizz   24 safe   29 guru
     5 cost   10 axis  15 heat   20 cost   25 dice

## Validation with seedtool

```bash
$ seedtool --version
0.9.0

$ seedtool --in sskr "tuna acid epic gyro cost gyro able acid also axis visa join yurt echo heat fuel iris judo fizz cost rock ugly soap safe dice cook slot next guru" "tuna acid epic gyro cost gyro able acid acid help whiz very stub join inky scar also jowl idea yawn gala huts what knob song zone cost into ugly"
8d969eef6ecad3c29a3a629280e686cf

$ seedtool --in dice 123456
8d969eef6ecad3c29a3a629280e686cf

$ seedtool --in dice 123456 | seedtool --in hex --out bip39
mirror reject rookie talk pudding throw happy era myth already payment owner
```

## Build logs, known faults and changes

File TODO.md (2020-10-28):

* Remove the ESP32 code from lethe.ino?

* Find a new supplier for keypads, costs $150 to ship $20 worth ...

* Can we make WordListState::wordndx a uint16_t? Would streamline.

* Add compatibility instructions for https://iancoleman.io/bip39/

* Add Security Considerations section to README.md, in particular talk
  about custody of device, evil maid attack, and tamper evident
  measures.

#### Semantic Versioning Reminder

Given a version number MAJOR.MINOR.PATCH, increment the:
* MAJOR version when you make incompatible API changes,
* MINOR version when you add functionality in a backwards compatible manner
* PATCH version when you make backwards compatible bug fixes.

#### Punchlist

Mark ksedgwic/seedtool (my old repo) as deprecated, point to lethekit.

#### Quality Checklist

* Correct version.

* Display alignment (selftest is most critical).

* Passes self-test.

* Both LEDs work.

* All keypad keys functional.

* No rattles.

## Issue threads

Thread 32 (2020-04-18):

Battery retention posts too thin

howech, 2020-04-18:
On the case, the posts that hold the battery in place are too weak. I received an assembled kit in the mail, and three of the four posts had broken off in transit.

ksedgwic, 2020-04-18:
I've seen one case of this as well; I dropped a unit from about 3ft up and it landed on the bottom edge.  The battery broke the bottom support off.

Fonta1n3, 2020-04-19:
Same issue here, its working great though.

ksedgwic, 2020-06-20:
Fixed in #33

Closed 2020-06-20.

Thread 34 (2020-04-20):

Display blank (Waveshare 200x200, 1.54inch E-Ink display Rev2.1)

bavarianledger, 2020-04-20:
I've assembled the Lethekit, compiled and uploaded the SeedTool. But no luck getting it to work.

What is the expected "boot behavior" of the LetheKit?
Has anyone created a short video showing the device powering up?

Mine is doing the following: blue LED turns on after powering it up, after ~1 second both LEDs are on for ~10 seconds, then the green LED turns off; nothing is shown on the display.

ksedgwic, 2020-04-20:
The LED sequence indicates that the device is executing the initial self-test correctly.
1. If the bootstrap reaches the seedtool code we turn on both the blue and green LEDS.
2. During selftest the green LED is on until completion.  The 10 seconds sounds right to complete selftest.
3. During selftest the running tests are displayed on the display; it should not be blank.

So the strong indication is that the display (alone) is unhappy.  Please confirm the wiring between the display and the CPU.

You can confirm the system state and keypad (with the non-functioning display) currently by typing the following things (blind) after the initial bootup:
1. Power up, after the green light goes out press anything on the keypad once.
2. Press 'A' (Generate Seed)
3. Press '#' (Done, seed created w/ blank entropy)
At this point the green LED should come back on.  If it does problem is isolated to display.

ChristopherA, 2020-04-20:
Are you certain that you've added code using the boot loader?

I personally have found it sometimes challenging to use the power-switch to get into bootloader mode. I found it it best to put two fingers on each side of the switch, start with the switch off and count fast 1-2-3 in about a second. Both blue & green lights will now be off despite the LetheKit being on.

-- Christopher Allen

bavarianledger, 2020-04-20:
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

Yes, I think so.
I prefer entering the bootloader by pressing the reset button twice.
And I've seen Arduino uploading and verifying the flash - about 98500 bytes.
So I guess this should be fine?

ChristopherA, 2020-04-20:
>So I guess this should be fine?

Yes. Given that, my presumption is that the code is loaded, but like @ksedgwic said I suspect there is hardware display connection problem going on.

When I turn mine #LetheKit on, the blue LED light turns on and the paper display flashes full black twice. Then the green LED light also turns on and you see on the display "Running self tests:" at the top of the display, and the build number at the bottom, and then a scrolling list of self test starting with "seed generate", "bip39 generation", etc. to "TESTS PASSED". Then the green LED will go out leaving only the blue LED on. I've not stopwatch'ed it, but the green light for self-tests seems to be on about 10s.

Hope this last is useful. I'm not the hardware or Arduino expert on the team, learning just like you!

-- Christopher Allen

bavarianledger, 2020-04-20:
Thank you.
I noticed one difference while troubleshooting with @ksedgwic in my setup: the Waveshare E-Ink display says Rev2.1.

ksedgwic, 2020-04-20:
Thanks to debugging support from @bavarianledger, we've found the problem.

Waveshare has started shipping a new version of the display ("Rev2.1 on the silkscreen).  Patching the hardware.{h,ino} files w/ s/GxEPD2_154/GxEPD2_154_D67/g fixes the problem.  Unfortunately the new driver doesn't work with the old displays so we're going to suffer some build/setup instruction pain (PR on the way).

Thanks again to @bavarianledger for finding and helping to fix this problem!

ChristopherA, 2020-04-20:
I had started to put some software version numbers in my PR (https://github.com/BlockchainCommons/bc-lethekit/pull/29) — but I really don't have the background to finalize this PR as I don't have any previous Arduino experience. I'm glad to continue to test the Mac build, but the text changes in this PR really should be taken by someone else, ideally @ksedgwic but if not then @wolfmcnally.

ksedgwic, 2020-06-20:
This issue is significantly addressed by #35 and #36 which are subsumed into #44

Closed 2020-06-20.

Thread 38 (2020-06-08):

BIP39 and SLIP39 generated wallets do not match

ksedgwic, 2020-06-08:
The LetheKit seedtool application generates new wallets using dice
entropy to create BIP39 and SLIP39 recovery mnemonics. The BIP39 and
SLIP39 mnemonics represent valid wallets, but they are not the same
wallet.

This is a serious problem.  If both BIP39 and SLIP39 backups are
created at the same time and funds are placed in the BIP39 wallet the
SLIP39 backup will fail to recover the same wallet and the funds would
be lost.
#### Why is this the case?

Andrew Kozlik explains it well in this [GitHub comment](https://github.com/iancoleman/slip39/issues/1#issuecomment-563213494)

#### How can matching BIP39 and SLIP39 backups be made?

Andrew Kozlik explains (above) that in principle, SLIP39 shares which
are 59 words long could match a BIP39 mnemonic.  In practice SLIP39
shares of this length are non-standard and unlikely to be supported by
any devices or applications.  The extreme length is also significantly
painful to record and enter.

#### Impact on LetheKit/seedtool:

The desired feature of (standard) matching BIP39 and SLIP39 backups is
not possible.

The conversion of a BIP39 backup into a SLIP39 backup is not possible.

The conversion of a SLIP39 backup into a BIP39 backup is not possible.

LetheKit/seedtool can generate valid BIP39 and SLIP39 wallets but
should not allow generation of both at the same time or suggest it
can convert between the two.

LetheKit can restore SLIP39 backups, but a mechanism to export the
master secret (likely via QR code) would need to be added.

ChristopherA, 2020-06-08:
My deal breaker here is that losing the ability to round trip from BIP39<->seed<->shards means that wallets are locked in to supporting SLIP39 the way Satoshi Labs does it. With our current sharing method (which needs to be changed to not confuse with SLIP39), you are not locked in to the Trezor — if a particular wallet does not support shards, you can convert the shards back into the seed, then back to BIP39 to the alternative wallet.

Our sharing method also supports binary mode, which allows use with QR codes the the UR: scheme, as well as allowing the addition of optional but often useful metadata like birthday, channel detail, etc. Satoshi Labs was very much against any additional data as it would increase the size of the mnemonics.

I was fine with supporting SLIP39 if there was no compromise on the round trip, and some how we missed this in our F2F discussion in Prague.

If the community consensus is that SLIP39 is broadly committed to and supported enough to compromize round trip, I'll reluctantly support it but I'll need to tell everyone in #SmartCustody that it risks vendor-lock-in until other major vendors support it. In the meantime, we'll focus on the binary QR and sharding approaches https://github.com/BlockchainCommons/Research/blob/master/papers/bcr-0005-ur.md

/cc @wolfmcnally @maaku @howech

-- Christopher Allen

secinthenet, 2020-12-29:
@ChristopherA maybe you're already aware of it, but SLIP39 doesn't specify what secret you split. The doc only says "SSS splits a master secret, such as the master seed S for Hierarchical Deterministic Wallets described in BIP-0032". So, using the master seed S is the example given (and the implementation in Trezor as I understand it), but another option it to split the initial entropy in BIP39, making it possible to round trip between the two.
That is, you can use the following scheme to make SLIP39 compatible:

SLIP39 shards <-->  BIP39 entropy <--> BIP39 mnemonic

I'll also ask Trezor folks to verify.

ksedgwic, 2020-12-29:
@secinthenet

> SLIP39 shards <--> BIP39 entropy <--> BIP39 mnemonic

This is exactly what we do.  But since you cannot restore to the same wallet on a SLIP39 device (ie Trezor) we call it "SSKR" instead.

secinthenet, 2020-12-30:
@ksedgwic to confirm, you're using the exact same method with the exact same crypto, just on the BIP39 initial entropy (which can be converted to and from the mnemonic) instead of the BIP32 master seed?
Which means for example that you can use bc-seedtool to encrypt a secret, and decrypt it with any SLIP39 library?

If that's indeed the case, it's good, because it makes it possible to reuse existing implementations of SLIP39. And I agree a different name is probably better to avoid

andrewkozlik, 2020-12-30:
> > SLIP39 shards <--> BIP39 entropy <--> BIP39 mnemonic
>
> This is exactly what we do. But since you cannot restore to the same wallet on a SLIP39 device (ie Trezor) we call it "SSKR" instead.

We would also advise using a different _customization string_ for the RS1024 [checksum](https://github.com/satoshilabs/slips/blob/master/slip-0039.md#checksum) to ensure that SSKR shares are not mistaken for SLIP39 shares, as noted in the [Versioning section](https://github.com/satoshilabs/slips/blob/master/slip-0039.md#versioning) of SLIP39. The current specification uses the customization string "shamir", see [Format of the share mnemonic](https://github.com/secinthenet/slips/blob/slip39-specify-bip32-backups/slip-0039.md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).

ksedgwic, 2020-12-30:
> @ksedgwic to confirm, you're using the exact same method with the exact same crypto, just on the BIP39 initial entropy (which can be converted to and from the mnemonic) instead of the BIP32 master seed?

Yes, this is what is done.

> Which means for example that you can use bc-seedtool to encrypt a secret, and decrypt it with any SLIP39 library?

The `bc-seedtool-cli` repo is a better place to ask, but I believe the answer is yes.  We should explicitly test this before advertising it as a feature, of course.

alandefreitas, 2021-11-12:
Hi @ksedgwic

I just happened to see this issue as we were discussing related issues in https://github.com/trezor/python-shamir-mnemonic/issues/40, and https://github.com/BlockchainCommons/seedtool-cli/issues/64. https://github.com/BlockchainCommons/seedtool-cli/issues/63 also discusses SLIP-0039 / BIP-0039 integration.

In our initial discussion in the SLIP-0039 reference implementation repository https://github.com/trezor/python-shamir-mnemonic/issues/40, we basically reach the conclusion that SLIP39 not supporting BIP39 was just a design choice. An unfortunate design choice in my opinion. I've forked the SLIP-0039 repo and implemented a prototype for BIP39/SLIP39 integration in [alandefreitas/python-shamir-bip39](https://github.com/alandefreitas/python-shamir-bip39).

I hope any of that is useful.

aido, 2021-12-14:
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

Hi,

Will [SSKR](https://github.com/BlockchainCommons/Research/blob/master/papers/bcr-2020-011-sskr.md) be offered as a BIP?

AnonymousAard, 2022-07-04:
Is there some way to use this to also store a BIP39 passphrase with the seedphrase?

ChristopherA, 2022-07-04:
We are planning to work this summer on the ability to also do `crypto-envelope` with SSKR, which will allow additional information to be encrypted and sharded with the seed. This can be the BIP-38 passphrase, optional metadata like key birthday, name, or even things like descriptors or lightning channels.

However, this feature will make for larger URs, so are best for QR, not Bytewords on steel or titanium.

If you are a software engineer and want to help with this project (specs, coding, testing, or docs), we are starting the week of July 10th.

mindrunner, 2023-02-05:
@ChristopherA Have you made any progress, yet? Do you still need developers? I would like to join :)

ChristopherA, 2023-07-11:
@mindrunner We have the envelope version of SSKR available in the Test Flight beta of our reference app Gordian Seed Tool (see last weeks Gordian Developers Meeting, summary at https://github.com/BlockchainCommons/Gordian-Developer-Community/discussions/114 and video on YouTube)

Are you still interested in helping out?

mindrunner, 2023-08-06:
Generally interested. Limited in time due to work, tho. Let's have a sync and talk about the needs and how I could help out!

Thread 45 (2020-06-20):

Display blank; doesn't seem to reset

ksedgwic, 2020-06-20:
This is a tracking bug to see if this problem is still present after #34

Originally reported and further researched by @gorazdko in #36

Please add a comment to this issue if you see this problem.  Please include the software version number and display hardware version (legacy or v2.1) if possible,

ksedgwic, 2020-06-20:
https://github.com/BlockchainCommons/bc-lethekit/pull/36#issuecomment-644212803

gorazdko, 2020-06-24:
The bug happens occasionally.

The highlighted code looks problematic to me. The hardware reset does not happen on power on, but only after hibernation sleep. I checked the spec and reference code (https://github.com/waveshare/e-Paper/blob/853a3a4632fcb64a215e5335700f512b692bee91/Arduino/epd1in54_V2/epd1in54_V2.cpp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) and both suggest HW reset must be there.

I will test this once I come across the bug next time - it sometimes happen after lethekit has been on the shelf for a long time.

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

ksedgwic, 2020-06-24:
@gorazdko I have a display that is still blank.  I swapped it out because I couldn't recover it by power cycling, reconnecting etc.  It is always possible it is broken, however.

What is your recommended fix to try?  Should I remove the `if (_hibernating)` predicate and always `_reset()` in that routine?

gorazdko, 2020-06-24:
> Should I remove the if (_hibernating) predicate and always _reset() in that routine?

That would be my guess, but i can't test because mine is working atm

The fastest way to see if the screen is working is by poking the vcc line during the selftest execution. Try also poking sck and mosi if vcc does not give results.

ksedgwic, 2020-06-24:
I connected the previously blank display to a unit running the current master build (v0.4.6-g13c1cf9), was hoping to see it remain blank so i could see if your patch fixed it.

Of course it now works w/o trying the patch ;-)

I made a WIP PR with this change so we can try it easily when we see it next: #47

gorazdko, 2020-10-05:
I think we can close this issue.

I haven't noticed any problems with the display and have been using it for quite a while now.

That one time i reported it, it must've been due to loose wiring.

ksedgwic, 2020-10-08:
I also haven't seen the problem again.  Closing for now.

Closed 2020-10-08.

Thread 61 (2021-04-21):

Question about choice of microcontroller

msgilligan, 2021-04-21:
Why was the SparkFun Thing Plus - SAMD51 chosen? Is there any public documentation about the reasons for this choice.

Would it be possible to build the LetheKit with the $4 Raspberry Pi Pico? If not, why?

I'm asking for two reasons:
1. To better understand the current design decisions
2. I'm tempted to try to see if I can port this to the RP2040/Pico

gorazdko, 2021-04-23:
> Why was the SparkFun Thing Plus - SAMD51 chosen? Is there any public documentation about the reasons for this choice?

I don't know about the reasons, @ksedgwic is the  original author who came up with the setup.

> Would it be possible to build the LetheKit with the $4 Raspberry Pi Pico? If not, why?

This could be doable if you stay within Arduino environment, otherwise I dont think it will be that easy.

Note also that lethekit uses cortex m4 whereas rpi uses m0+, so some compiling difficulties may arise from that. And wrt to resources (gpios, RAM, peripherals) I'd say the rpi should handle it.

ksedgwic, 2021-04-23:
@msgilligan We were looking for an Arduino compatible device that didn't have radios (Bluetooth, WiFi, ..)

ksedgwic, 2021-04-23:
I'm not a fan of the TRNG part anyway, I think all the entropy should be generated with dice.  Everything else is very portable ...

msgilligan, 2021-04-23:
Thanks for the responses, @gorazdko and @ksedgwic!

The Pico doesn't have any radios, either. So it should be a good choice if it can be made to work. ($16 cheaper)

I've ordered the SAMD51 and the other major components and will try to build one. I'm experimenting with the Pico on another project. I may try to see if I can get the code to run on the Pico. I believe the Pico works with the Arduino environment, so it might not be that difficult.

ksedgwic, 2021-04-23:
A big component of the price of the Thing Plus is the battery charging circuit.  If you can live w/o the battery things can be significantly cheaper.  Alternatively, if there was sufficient interest (quantity) it would make sense to design a PC board with the charging circuit provided externally.  A PC board would also simplify the assembly and make the result much more rugged ....

msgilligan, 2021-04-23:
So with the Pico, you'd have to use a power adapter or a disposable battery pack?

gorazdko, 2021-04-23:
> So with the Pico, you'd have to use a power adapter or a disposable battery pack

yes. You could also use rechargable batteries but you won't be able to recharge them via the board's usb

> There is also this board available

this one supports charging, but it's also more expensive

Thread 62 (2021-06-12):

manufacturability warnings for cover.stl at hubs.com

aaronferrucci, 2021-06-12:
I uploaded the 3 STL files to a 3D printing service, hubs.com. For the cover, I get a manufacturability warning: "mesh integrity: 127 intersecting faces". I tried two different processes, MJF and SLS, both using nylon, and the same warning occurs.

There's a second warning that seems less severe, "thin walls"; the report says this would be reviewed manually.

Does anyone know if these warnings can be ignored? Alternatively, has anyone successfully printed the case at a printing service? (If so, please provide the URL.)

gorazdko, 2021-06-13:
> Alternatively, has anyone successfully printed the case at a printing service? (If so, please provide the URL.)

Yes I have, at my local printing service

I don't know about the particular problem you are mentioning but googling suggests it's (often) a false positive on hubs.com, e.g.

https://forums.autodesk.com/t5/fusion-360-support/every-single-stl-file-i-export-has-quot-intersecting-faces-quot/m-p/8943660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

I'd ignore the warnings if it lets you.

@ksedgwic do you have any thoughts?

ksedgwic, 2021-06-14:
Nothing obvious comes to mind.

aaronferrucci, 2021-06-15:
Someone from hubs.com got in touch with me. They reviewed the design, and said that it should print fine (the "intersecting faces" warnings can be ignored). I'm trying to print it. I will post my notes here as things happen.

aaronferrucci, 2021-07-03:
Case from hubs.com arrived, looks good. Seems that the warning from hubs.com's automatic checks is spurious (and they're aware of the issue). Closing this case.

ChristopherA, 2021-07-04:
@aaronferrucci If you have any notes you’d like to share as PR with advice on using our designs with various third-party serviced, it would be greatly appreciated.

Closed 2021-07-03.

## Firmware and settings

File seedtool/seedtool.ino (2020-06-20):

// Copyright © 2020 Blockchain Commons, LLC

#include "hardware.h"
#include "selftest.h"
#include "seed.h"
#include "userinterface.h"
#include "util.h"

#include "gitrevision.h"

void setup() {

    hw_setup();

    // To see the serial debugging output from the power-on-self-test
    // uncomment this delay to give you a chance to get the serial
    // monitor launched before the tests run.
    //
    // delay(5000);

    ui_reset_into_state(SELF_TEST);

    Serial.println("seedtool starting");
}

void loop() {
    ui_dispatch();
}

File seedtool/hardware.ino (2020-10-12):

// Copyright © 2020 Blockchain Commons, LLC

// Only define one of these
#undef ESP32
#define SAMD51	1

#define ENABLE_GxEPD2_GFX 1
#include <GxEPD2_BW.h>

#include "hardware.h"
#include "util.h"

#if defined(SAMD51)
extern "C" {
#include "trngFunctions.h"
}
#endif

/*
 *  Epaper PIN MAP: [
 *            ESP32     SAMD51
 * ---------------------------
 *      VCC - 3.3V      3.3V
 *      GND - GND       GND
 *      SDI - GPIO18    23/MOSI
 *     SCLK - GPIO5     24/SCK
 *       CS - GPIO21    A4
 *      D/C - GPIO17    A3
 *    Reset - GPIO16    A2
 *     Busy - GPIO4     A1
 *  ]
 *
 *  Keypad Matrix PIN MAP: [
 *            ESP32     SAMD51
 * ---------------------------
 *     Pin8 - GPIO13    13
 *        7 - GPIO12    12
 *        6 - GPIO27    11
 *        5 - GPIO33    10
 *        4 - GPIO15    9
 *        3 - GPIO32    6
 *        2 - GPIO14    5
 *     Pin1 - GPIO22    21/SCL
 *  ]
 *
 *  BLUE LED PIN MAP: [
 *                      ESP32       SAMD51
 * ---------------------------------------
 *    POS (long leg)  - GPIO25      1
 *    NEG (short leg) - GND         GND
 *  ]
 *
 *  GREEN LED PIN MAP: [
 *                      ESP32       SAMD51
 * ---------------------------------------
 *    POS (long leg)  - GPIO26      4
 *    NEG (short leg) - GND         GND
 *  ]
 */

// LEDS
#if defined(ESP32)
#define BLUE_LED	25
#define GREEN_LED	26
#elif defined(SAMD51)
#define BLUE_LED	1
#define GREEN_LED	4
#endif

GxEPD2_GFX *g_display;

// Display
#if defined(ESP32)
GxEPD2_BW<EPD_DRIVER, EPD_DRIVER::HEIGHT>
g_display(EPD_DRIVER(/*CS=*/   21,
                     /*DC=*/   17,
                     /*RST=*/  16,
                     /*BUSY=*/ 4));
#elif defined(SAMD51)

// Around April 2020 Waveshare started shipping a new version of the
// "Waveshare 200x200, 1.54inch E-Ink display module".  The new
// versions have "Rev2.1" printed under the title on the circuit side
// of the display.  This new version requires a different driver
// module from GxEPD2 (GxEPD2_154_D67).
//
// We declare and initialize both modules and then probe the
// controller at runtime to see which is connected.
//
GxEPD2_BW<GxEPD2_154, GxEPD2_154::HEIGHT>
display_legacy(GxEPD2_154(/*CS=*/   PIN_A4,
                          /*DC=*/   PIN_A3,
                          /*RST=*/  PIN_A2,
                          /*BUSY=*/ PIN_A1));
GxEPD2_BW<GxEPD2_154_D67, GxEPD2_154_D67::HEIGHT>
display_modern(GxEPD2_154_D67(/*CS=*/   PIN_A4,
                              /*DC=*/   PIN_A3,
                              /*RST=*/  PIN_A2,
                              /*BUSY=*/ PIN_A1));
#define SW_SCK 24
#define SW_MOSI 23
#endif

// Keypad
const byte rows_ = 4;
const byte cols_ = 4;
char keys_[rows_][cols_] = {
                         {'1','2','3','A'},
                         {'4','5','6','B'},
                         {'7','8','9','C'},
                         {'*','0','#','D'}
};
#if defined(ESP32)
byte rowPins_[rows_] = {13, 12, 27, 33};
byte colPins_[cols_] = {15, 32, 14, 22};
#elif defined(SAMD51)
byte rowPins_[rows_] = {13, 12, 11, 10};
byte colPins_[cols_] = {9, 6, 5, 21};
#endif

Keypad g_keypad = Keypad(makeKeymap(keys_), rowPins_, colPins_, rows_, cols_);

void hw_setup() {
    pinMode(BLUE_LED, OUTPUT);	// Blue LED
    digitalWrite(BLUE_LED, HIGH);

    pinMode(GREEN_LED, OUTPUT);	// Green LED
    digitalWrite(GREEN_LED, LOW);

    Serial.begin(115200);

    // Initialize both versions of the display instance.
    display_modern.epd2.init(SW_SCK, SW_MOSI, 115200, true, false);
    display_modern.init(115200);
    display_legacy.epd2.init(SW_SCK, SW_MOSI, 115200, true, false);
    display_legacy.init(115200);

    // Read a byte from the display instance to pick a version.
    uint8_t read_legacy = display_legacy.epd2._readData();
    serial_printf("read_legacy: readData=0x%02x\n", read_legacy);
    g_display = read_legacy
        ? static_cast<GxEPD2_GFX *>(&display_legacy)
        : static_cast<GxEPD2_GFX *>(&display_modern);

    // Switch back to HW SPI for performance.
    g_display->epd2.init(-1, -1, 115200, true, false);

    g_display->setRotation(1);

#if defined(SAMD51)
    trngInit();
#endif

    // Only wait on the ESP32, the SAMD51 gets hung w/o serial here
#if defined(ESP32)
    while (!Serial);	// wait for serial to come online
#endif
}

void hw_green_led(int value) {
    digitalWrite(GREEN_LED, value);  // turn off the green LED
}

extern "C" {

void hw_random_buffer(uint8_t *buf, size_t len) {
    serial_printf("random_buffer %d\n", len);
    uint32_t r = 0;
    for (size_t i = 0; i < len; i++) {
        if (i % 4 == 0) {
#if defined(ESP32)
            r = esp_random();
#elif defined(SAMD51)
            r = trngGetRandomNumber();
#endif
        }
        buf[i] = (r >> ((i % 4) * 8)) & 0xFF;
    }
}


// TODO
void random_buffer(uint8_t *buf, size_t len, void * p) {
    if (p == NULL) {
        hw_random_buffer(buf, len);
    }
    else {
      // deterministic random
      // TODO
    }
  
}


} // extern "C"

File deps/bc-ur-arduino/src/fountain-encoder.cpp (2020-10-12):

//
//  fountain-encoder.cpp
//
//  Copyright © 2020 by Blockchain Commons, LLC
//  Licensed under the "BSD-2-Clause Plus Patent License"
//

#include "fountain-encoder.hpp"
#include <assert.h>
#include <cmath>
//#include <optional>
#include <vector>
//#include <limits>
//#include "cbor-lite.hpp"
#include <ArduinoSTL.h>
#include <Arduino.h>
#include <string>
#include "CborEncoder.h"
#include "CborDecoder.h"

//#include "util.h"


using namespace std;

namespace ur_arduino {

class CborListen_Part : public CborListener {
  public:
    void OnInteger(int32_t value){Serial.println("integer"); integers[i] = value; i++; Serial.println(value); };
    void OnBytes(unsigned char *data, unsigned int size) {Serial.println("bytes");};
    void OnString(String &str) {Serial.println("string");};
    void OnArray(unsigned int size) {Serial.println("array");};
    void OnMap(unsigned int size) {Serial.println("map");};
    void OnTag(uint32_t tag) {Serial.println("tag");};
    void OnSpecial(uint32_t code) {Serial.println("tag");};
    void OnError(const char *error) {Serial.println("error");};
    
    // we are gonna collect 4 integers: seqnum, seqlen, msglen and checksum
    size_t i = 0;
    uint32_t integers[4];
};

size_t FountainEncoder::find_nominal_fragment_length(size_t message_len, size_t min_fragment_len, size_t max_fragment_len) {
    assert(message_len > 0);
    assert(min_fragment_len > 0);
    assert(max_fragment_len >= min_fragment_len);
    auto max_fragment_count = message_len / min_fragment_len;
    size_t fragment_len = 0;
    for(size_t fragment_count = 1; fragment_count <= max_fragment_count; fragment_count++) {
        fragment_len = size_t(ceil(double(message_len) / fragment_count));
        if(fragment_len <= max_fragment_len) {
            break;
        }
    }
    assert(fragment_len > 0);
    return fragment_len;
}

vector<ByteVector> FountainEncoder::partition_message(ByteVector message, size_t fragment_len) {
    auto remaining = message;
    vector<ByteVector> fragments;
    while(!remaining.empty()) {
        auto a = split(remaining, fragment_len);
        auto fragment = a.first;
        remaining = a.second;
        auto padding = fragment_len - fragment.size();
        while(padding > 0) {
            fragment.push_back(0);
            padding--;
        }
        fragments.push_back(fragment);
    }
    return fragments;
}

FountainEncoder::Part::Part(const ByteVector& cbor) {
        Serial.println("*******   Part::Part(const ByteVector& cbor)    ********");

    uint8_t* cbor_arr = (uint8_t *)&cbor[0];
    CborInput input(cbor_arr, cbor.size());
    CborReader reader(input);
    CborListen_Part listener;
    reader.SetListener(listener);
    reader.Run();

    seq_num_ = listener.integers[0];
    seq_len_ = listener.integers[1];
    message_len_ = listener.integers[2];
    checksum_ = listener.integers[3];

    Serial.println("seq_num_:");
    Serial.println(seq_num_);

    Serial.println("seq_len_:");
    Serial.println(seq_len_);

    Serial.println("message_len_:");
    Serial.println(message_len_);

    Serial.println("checksum_:");
    Serial.println(checksum_);
}

ByteVector FountainEncoder::Part::cbor() const {
    //using namespace CborLite;  // TODO!!!!!!!!!!!!!!!!!!1

    CborDynamicOutput output;
    CborWriter writer(output);

    writer.writeArray(5);
    writer.writeInt(seq_num());
    writer.writeInt((uint32_t)seq_len());
    writer.writeInt((uint32_t)message_len());
    writer.writeInt(checksum());

    ByteVector dat = data();
    uint8_t *d = &dat[0];
    writer.writeBytes(d, data().size());

    ByteVector result(output.getData(), output.getData() + output.getSize());

    return result;
}

FountainEncoder::FountainEncoder(const ByteVector& message, size_t max_fragment_len, uint32_t first_seq_num, size_t min_fragment_len) {
    assert(message.size() <= UINT32_MAX);
    message_len_ = message.size();
    checksum_ = crc32_int(message);
    fragment_len_ = find_nominal_fragment_length(message_len_, min_fragment_len, max_fragment_len);
    fragments_ = partition_message(message, fragment_len_);
    seq_num_ = first_seq_num;
}

ByteVector FountainEncoder::mix(const PartIndexes& indexes) const {
    ByteVector result(fragment_len_, 0);
    for(auto index: indexes) { xor_into(result, fragments_[index]); }
    return result;
}

FountainEncoder::Part FountainEncoder::next_part() {
    seq_num_ += 1; // wrap at period 2^32
    auto indexes = choose_fragments(seq_num_, seq_len(), checksum_);
    auto mixed = mix(indexes);
    return Part(seq_num_, seq_len(), message_len_, checksum_, mixed);
}

string FountainEncoder::Part::description() const {
    string seq_num_str = (String(seq_num_)).c_str();
    string seq_len_str = (String(seq_len_)).c_str();
    string message_len_str = (String(message_len_)).c_str();
    string checksum_str = (String(checksum_)).c_str();
 
    return "seqNum:" + seq_num_str + ", seqLen:" + seq_len_str + ", messageLen:" + message_len_str + ", checksum:" + checksum_str + ", data:" + data_to_hex(data_);
}

}

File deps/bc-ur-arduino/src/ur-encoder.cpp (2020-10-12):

//
//  ur-encoder.cpp
//
//  Copyright © 2020 by Blockchain Commons, LLC
//  Licensed under the "BSD-2-Clause Plus Patent License"
//

#include "ur-encoder.hpp"
#include "bytewords.hpp"

using namespace std;

namespace ur_arduino {

string UREncoder::encode(const UR& ur) {
    auto body = Bytewords::encode(Bytewords::style::minimal, ur.cbor());
    return encode_ur({ur.type(), body});
}

UREncoder::UREncoder(const UR& ur, size_t max_fragment_len, uint32_t first_seq_num, size_t min_fragment_len)
    : ur_(ur),
    fountain_encoder_(FountainEncoder(ur.cbor(), max_fragment_len, first_seq_num, min_fragment_len))
{
}

std::string UREncoder::next_part() {
    auto part = fountain_encoder_.next_part();
    if(is_single_part()) {
        return encode(ur_);
    } else {
        return encode_part(ur_.type(), part);
    }
}

string UREncoder::encode_part(const string& type, const FountainEncoder::Part& part) {
    char seq[200] = {0};
    sprintf(seq, "%d-%d", part.seq_num(), part.seq_len());
    //auto seq = to_string((int32_t)part.seq_num()) + "-" + to_string(part.seq_len());
    auto body = Bytewords::encode(Bytewords::style::minimal, part.cbor());
    return encode_ur({type, seq, body});
}

string UREncoder::encode_uri(const string& scheme, const StringVector& path_components) {
    auto path = join(path_components, "/");
    return join({scheme, path}, ":");
}

string UREncoder::encode_ur(const StringVector& path_components) {
    return encode_uri("ur", path_components);
}

}

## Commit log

2020-03-26 Added 3D and Arduino source files.
    [body.stl, case.blend, cover.stl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]
2020-03-27 Added NOTES w/ sample data.
2020-03-27 Mods to support Arduino workflow.
2020-03-28 Added assembly instructions.
2020-03-28 Fixes to the assembly instructions.
2020-03-28 Tweaked assembly photo.
2020-03-28 Added case and arduino docs.
2020-03-29 Fixed docs, updated version string.
    [seedtool.ino]
2020-03-31 Started w/ fresh Arduino Sketchbook, updated installation and docs.
2020-04-01 Fixed rename bug in lethekit -> arduino install.
2020-04-02 Updated CLA.ChristopherA…
2020-04-02 Added power-on-self-test screen before intro screen. Added disable-gitrevision-hooks.sh
2020-04-02 Clarified & linked 3D print parts
2020-04-06 Added BIP39 wordlist error screen.
    [userinterface.ino]
2020-04-06 Added SLIP39 share checksum validation, del_share and self tests.
    [seed.ino, selftest.ino, userinterface.ino]
2020-04-06 Added SLIP39 diagnostic GUI.
    [seed.ino, selftest.ino, userinterface.ino]
2020-04-06 Added "hold any key to skip remaining self tests.
    [userinterface.ino]
2020-06-20 Fixed compiler warnings specific to the develop branch.
    [selftest.ino]
2020-06-20 Made "Waveshare Rev2.1" the default display driver.
2020-06-20 Use GxEPD2/extras/sw_spi to probe controller and switch between legacy and modern epaper displays.
2020-06-20 Vendored GxEPD2 (forked to use SW SPI) as submodule dependency.
2020-06-20 Fixed bip39 dictionary word lookup botch.
    [selftest.ino, userinterface.ino]
2020-07-10 create arduino library.properties for libwally
2020-07-17 fix doc: remove gxepd2 lib from arduino installation
2020-07-18 implement xpub menu with options: derivation path, slip132
    [keystore.ino, userinterface.ino]
2020-08-01 add crypto-seed test and fix memory issues
    [selftest.ino, ur.ino]
2020-08-01 xpub: implement derivation path option fix minor leaks
    [keystore.ino, userinterface.ino]
2020-08-10 add error screen and check return values plus another bugfix and resolve compiler warnings
    [keystore.ino, ur.ino, userinterface.ino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]
2020-08-14 minor fix: show URs in lower case
    [ur.ino, userinterface.ino]
2020-08-16 slip39: implement ur export option
    [ur.ino, userinterface.ino]
2020-08-25 fix: cbor of crypto-hdkey
    [keystore.ino, ur.ino, userinterface.ino]
2020-08-25 fix: derive bip32 root key from bip39 mnemonic seed, fingerprint endianess, slip132
    [keystore.ino, seed.ino, ur.ino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]
2020-09-20 fix segwit derivation. Not tested yet
    [userinterface.ino]
2020-09-20 fixup! export wallet in different formats
    [userinterface.ino]
2020-10-05 update bytewords in bc-ur-arduino
2020-10-09 add ArduinoSTL submodule
2020-10-20 add install wizard to determine Arduino sketchbook location
2020-10-28 case v25: Strengthened the battery holders.
    [body.stl, case.blend]
2020-10-28 case-v26: Moved top battery holder to clear alternate display.
    [body.stl, case.blend]
2020-10-28 fix clipped text on the left side of the screen fix compiler warnings, some variables renamed
    [selftest.ino, test_bc_ur.ino, userinterface.ino]
2020-10-30 allow fixing bip39 checksum
    [userinterface.ino]
2021-02-05 xpriv: add ur and base58 encoding options. No slip132 for now.
    [seedtool.ino, ur.ino, userinterface.ino]
2021-02-06 add slip132 for xprivs
    [keystore.ino, userinterface.ino]
2021-07-04 Printing notes
    Added a Printing section, which could be filled in with notes from those who have printed the case. Added a table for printing services.
